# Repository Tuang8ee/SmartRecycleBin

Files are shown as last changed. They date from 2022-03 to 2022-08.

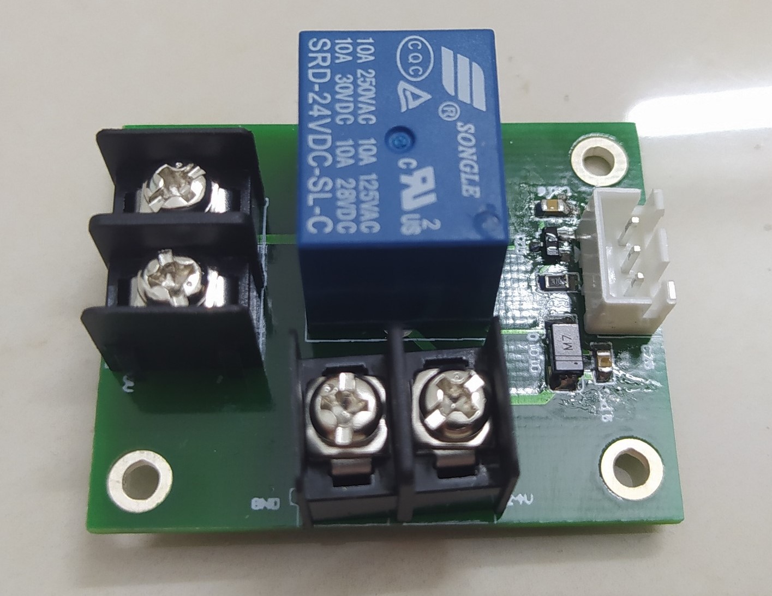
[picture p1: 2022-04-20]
Report/IMG/z3350971799940_279ff23e00b681c5e4f6fa2f28d8ae1a.jpg

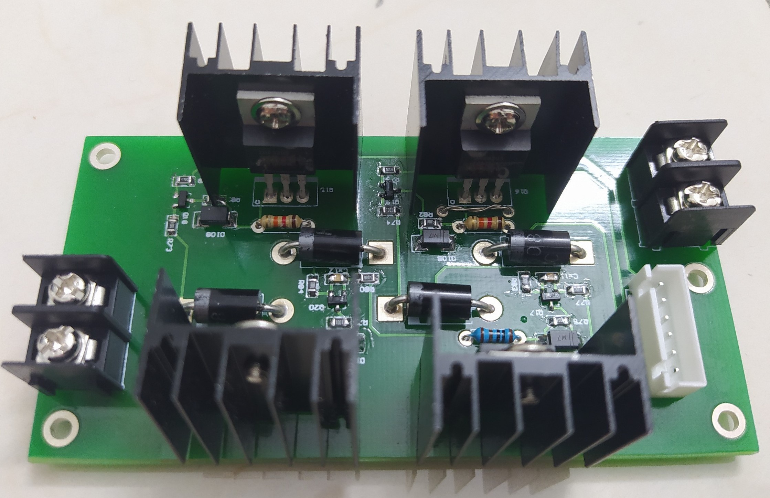
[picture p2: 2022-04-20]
Report/IMG/z3350971804815_c565af6ffac9c361b80e90f9cfdadc9c.jpg

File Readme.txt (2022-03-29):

Đây là git giúp việc gửi file và chia sẻ trong nhóm được dễ dàng hơn. 
Git này phục vụ cho dự án thùng rác thông minh. Mọi người vào nhớ chú ý sắp xếp theo thứ tự thư mục nha.
- Thư mục Report: Lưu lại file báo cáo, các vấn đề liên quan đến báo cáo.
- Thư mục Document: Liên quan đến các tài liệu, doc nếu có.
- Thư mục Project: Sẽ lưu các vấn đề liên quan đến dự án như mạch, thiết kế cơ khí, hay code. Bên trong có các thư mục con:
  + Code
  + Altium
  + CAD
Link data update:
- Link git: https://github.com/Tuang8ee/SmartRecycleBin.git
- Link driver: https://drive.google.com/drive/folders/1032KCYmue00TLKaejduGrtlUdy1hicEE?usp=sharing

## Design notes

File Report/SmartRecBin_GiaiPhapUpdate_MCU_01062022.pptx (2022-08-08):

## SmartRecBin

Dự tính Update mạch điều khiển.

## Giải pháp điều chỉnh mạch điều khiển.

IR Sensor

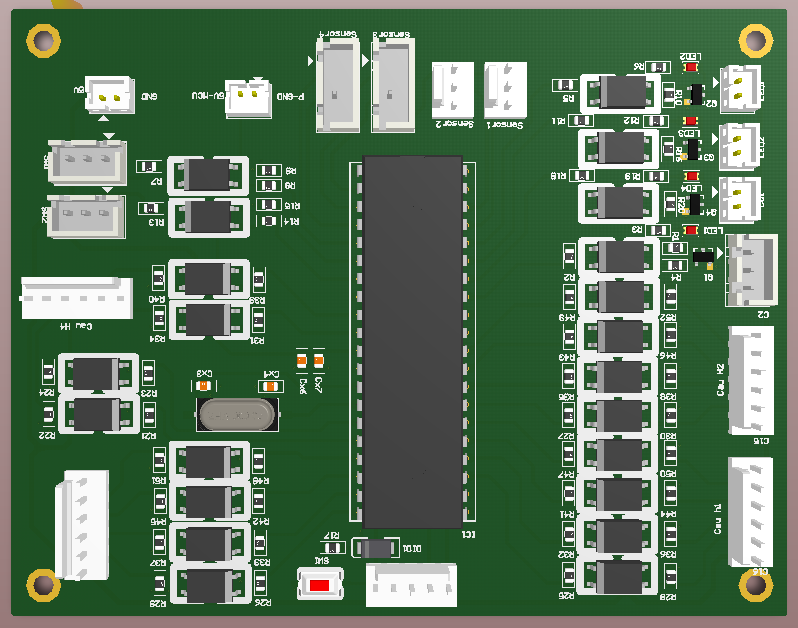
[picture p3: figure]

UltrasonicSensor

1 Buzzer
2 Led

Khử mùi

Button

H: Error

Tời

Compress Motor

UART: RX, TX

UART: RX, TX (TFT)

Door Motor

Hình 1.0: Hình ảnh thể hiện mạch MCU hiện tại và phương hướng phát triển.

Chú thích:

Bị lỗi

Không đổi

Đang dùng

Thay đổi dự kiến

## Giải pháp điều chỉnh mạch điều khiển.

- Chân chưa dung:
  - => Max: Còn 9 chân chưa dùng.
  - => Min: Còn 7 chân chưa dùng (trừ 2 chân I2C).
- Update cảm biến:
  - => Cảm biến LoadCell + HX711: 2 chân.
  - => Cảm biến tời: IR or tiệm cận: 1 chân.
  - => Công tắc hành trình nén: 1 chân.
  - => Công tắc hành trình cửa: 1 chân.
  - => 2 chân chờ Update thêm.
- => Làm mạch nhận tín hiệu cổng OR 2 chân => 1 chân.

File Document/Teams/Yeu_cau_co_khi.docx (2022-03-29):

Mô tả cơ cấu cơ khí nắp thùng rác

Thông tin cơ bản:

- Thông số thùng hiện tại: L:860mm * W:400mm * H:915mm (thân thùng chưa có nắp).
- Cần thiết kế nắp thùng rác cho ba loại thùng khác nhau để đáp ứng các nhu cầu sau:
  - Thùng 1: (T1) thùng đựng vỏ chai nhựa đồ nhựa nhũng rác thải với chất liệu bằng nhựa.
  - Thùng 2: (T2) thùng đựng vỏ lon coca pepsi… những loại rác thải kim loại.
  - Thùng 3: (T3) thùng đựng rác thải hữu cơ.

Mô tả yêu cầu thiết kế cơ khí cho 3 loại thùng rác.

Kích thước nắp thùng mong muốn:

Thông số nắp thùng mong muốn: L:860mm * W:400mm * H:~300mm.

+ Thùng rác (T1) (T2)

- Thùng rác T1, và T2 thiết kế cơ cấu nén rác, vị trí bỏ rác nằm bên cạnh thùng.
- Thiết kế nắp thùng rác gồm có cơ cấu nén rác và có vị trí để mạch nguồn, mạch điều khiển và một acquy 12V.
- Hình ảnh mô tả cơ cấu nén rác và vị đặt của của nắp thùng rác:

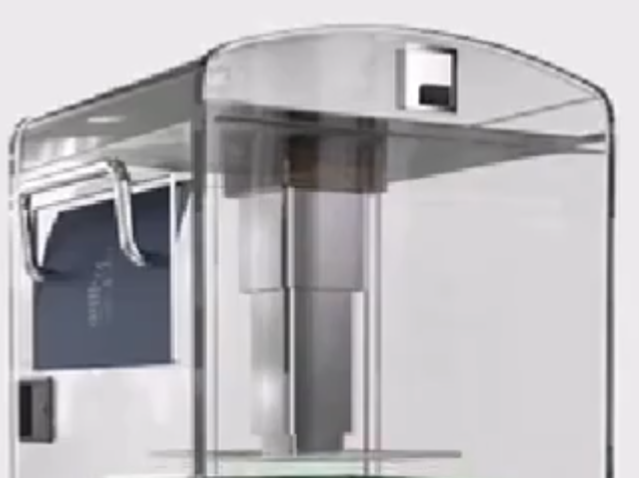
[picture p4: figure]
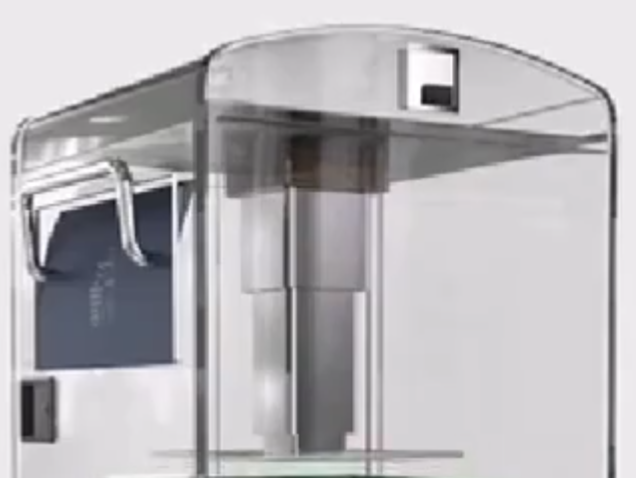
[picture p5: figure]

Khu vực bố trí động cơ mà mạch điều khiển, mạch nguồn, và bố trí acquy

Vị trí bố trí cửa thùng rác (khu vực nắp thùng

Phần cơ cấu nén rác bố trí trên nắp thùng rác

Vị trí bố trí cảm biếm báo đầy rác

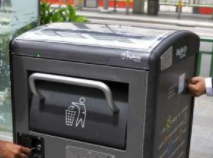
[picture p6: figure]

Phần tay nắm mở nắp thùng rác khi người dùng muốn bỏ rác vào thùng.

- Kiểu nắm mở nắp thùng rác khi người đến vứt rác sẽ kéo tay nắm để bỏ rác vào thùng.

+Thùng rác (T3)

- Thùng rác T3 không có phần nén rác, ở thùng rác T3 thiết kế mở nắp tự động khi có người đến vứt rác.

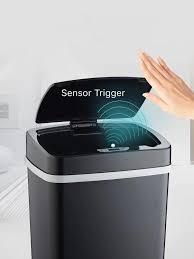
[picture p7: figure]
Automatic Dustbin, Furniture & Home Living, Cleaning & Homecare Supplies, Waste Bins & Bags on Carousell

Vị trí đặt cảm biến

Vị trí đặt cảm biến báo đầy rác

Hình ảnh mô tả cơ chế mở nắp thùng rác

_ Trên mặt thùng rác bố trí cảm biến để nhận biết khi có người đến đổ rác thùng rác sẽ tự động mở nắp.

_ Nắp thùng rác bố trí các vị trí động cơ điều khiển mở đóng nắp thùng rác tự động, vị trí các cảm biến, mạch điều khiển, mạch nguồn và acquy.

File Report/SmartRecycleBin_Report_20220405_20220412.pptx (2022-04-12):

## Thùng rác thông minh

Báo cáo 05/04/2022 – 12/04/2022
(Tuần 3)

## Nội dung thực hiện:

- Tiến hành đặt mạch in.
- Hoàn thành đặt linh kiện.
- Hoàn thiện file cơ khí.
- Bắt đầu viết chương trình điều khiển.

## Kết quả:

- Tiến hành đặt mạch in:
  - Cơ sở đặt mạch: VNPCB – HAVICOM.
  - Địa chỉ: Số 77 LK23 – KĐT Vân Canh HUD, Hoài Đức, Hà Nội.
  - Thời gian đặt mạch: 08/04 – 15/04. (4 – 5 ngày làm việc, nghỉ lễ giỗ tổ Hùng Vương nên bị chậm 3 ngày so với kế hoạch đẩy nhanh tiến độ tuần 2).
- Đặt linh kiện:
  - Đã tiến hành đặt và order linh kiện. Hiện tại đã đủ linh kiện để hoàn thành mạch khi mạch về.

## Kết quả:

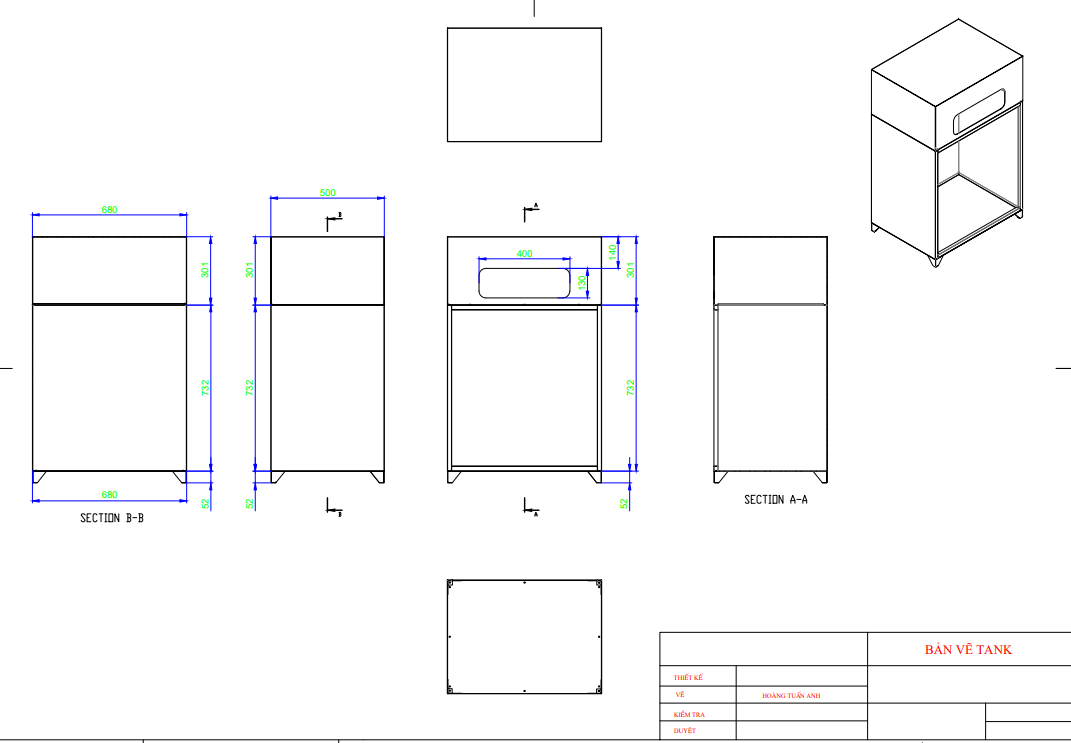
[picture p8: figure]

- Hoàn thiện file cơ khí:

Hình 1: Hình ảnh miêu tả bản vẽ cơ khí tổng quát thùng rác.

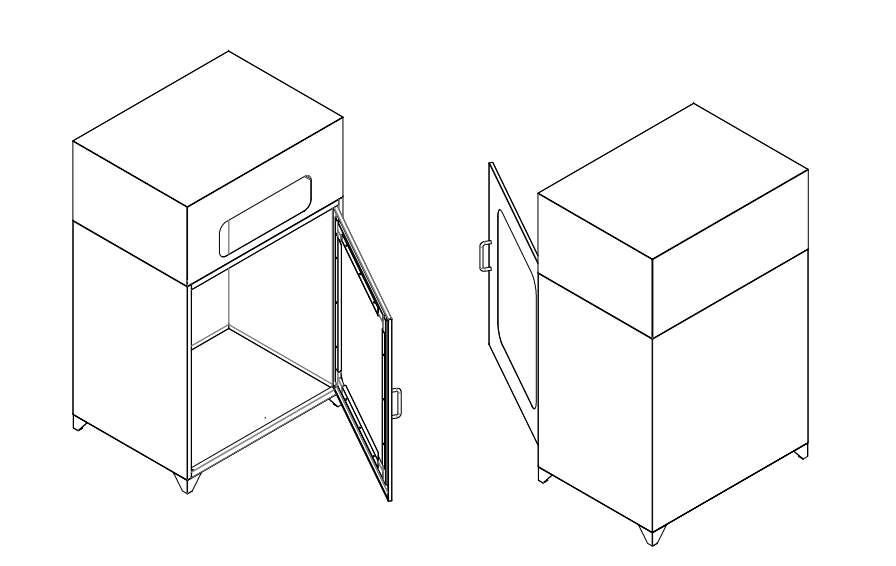
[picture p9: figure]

## Kết quả:

- Hoàn thiện file cơ khí:

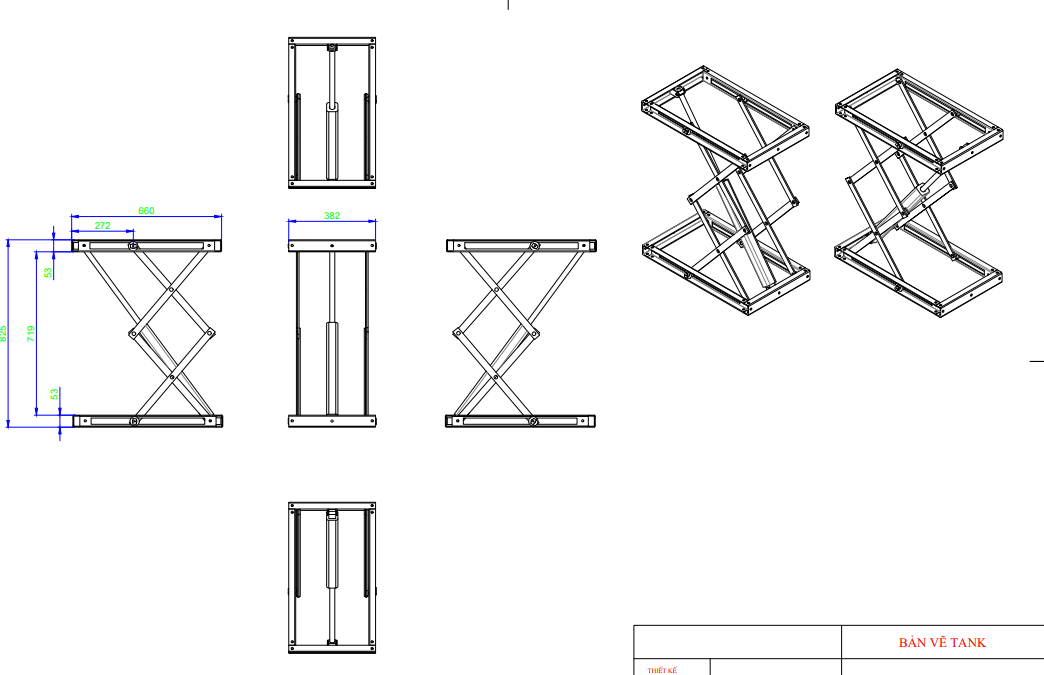
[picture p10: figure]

Hình 2: Hình ảnh miêu tả bản vẽ cơ khí một số phần của sản phẩm.

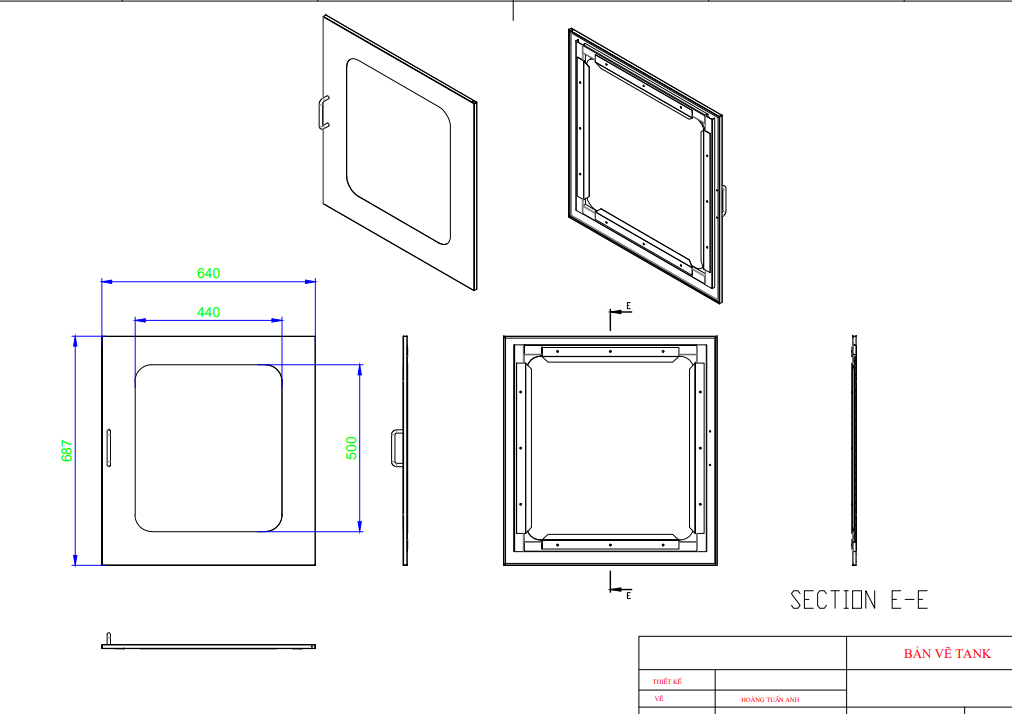
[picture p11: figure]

## Vấn đề còn gặp phải.

- Tiến độ dự án:
Hiện tại tiến độ dự án chậm hơn so với kế hoạch đặt ra, cụ thể:
Kế hoạch vẫn chậm hơn 8 ngày so với dự kiến. Trong giai đoạn đặt mạch không thể rút ngắn thêm thời gian. Vì thế thời gian dự kiến sẽ được update trong bảng timeline phía dưới.
- Nội dung dự án:
  - Còn một số vấn đề cần thống nhất trước khi gửi bản vẽ gia công cơ khí. Cụ thể:
    - Cần trao đổi và chốt một số phương án thiết kế chi tiết phía trong bản vẽ cơ khí.
    - Xác nhận thông số trước khi gửi thông tin bản thiết kế cho sản phẩm demo lần 1.

## Phương án giải quyết và kế hoạch tiếp theo.

- Đề xuất phương án:
  - Trao đổi thống nhất một số thông số chung trước khi gửi file hoàn thiện.
  - Update timeline mới:
- Kế hoạch tuần tiếp theo:
  - Hoàn thiện mạch, sẵn sàng cho sản phẩm demo.
  - Gia công cơ khí.
  - Chuẩn bị kịch bản test và demo.

## Phương án giải quyết và kế hoạch tiếp theo.

  - Update timeline mới:

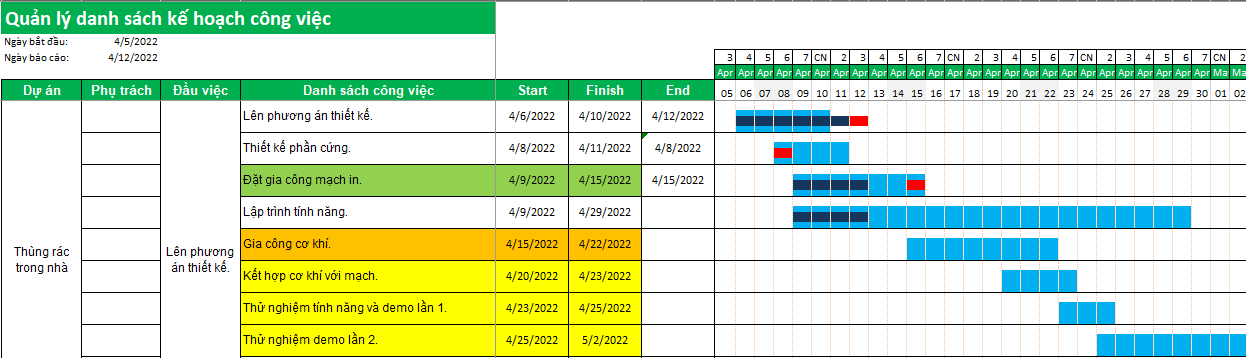
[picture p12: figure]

Hình 3: Hình ảnh miêu tả bản update timeline dự kiến cho thời gian tới.

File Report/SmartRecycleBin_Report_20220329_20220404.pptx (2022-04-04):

## Thùng rác thông minh

Báo cáo 29/03/2022 – 04/04/2022

## Nội dung thực hiện:

- Hoàn thành sơ đồ nguyên lý của mạch. Hoàn thành bản vẽ bố trí linh kiện, mô phỏng 3D mạch.
- Đưa ra phương án thiết kế cơ cấu nén rác, cắt nhỏ, nghiền cho thùng rác chưa túi nilon, thùng rác chứa vỏ lon và vỏ chai nhựa.
- Chuẩn bị linh kiện, động cơ cho sản phẩm.

## Kết quả:

- Hoàn thành sơ đồ nguyên lý của mạch. Hoàn thành bản vẽ bố trí linh kiện, mô phỏng 3D mạch:

## Kết quả:

- Phương án thiết kế bộ phận nén cho thùng rác túi nilon: Thiết kế cơ cấu nén rác theo cơ cấu hình chữ X:

Hình 1: Hình ảnh miêu tả ý tưởng thiết kế cơ chế nén thùng rác.

Thùng rác nilon

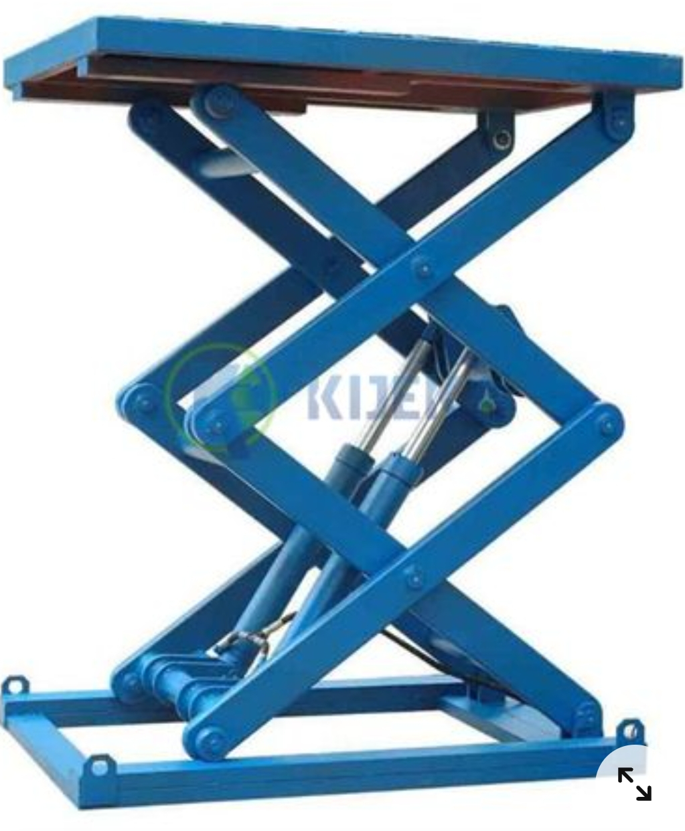
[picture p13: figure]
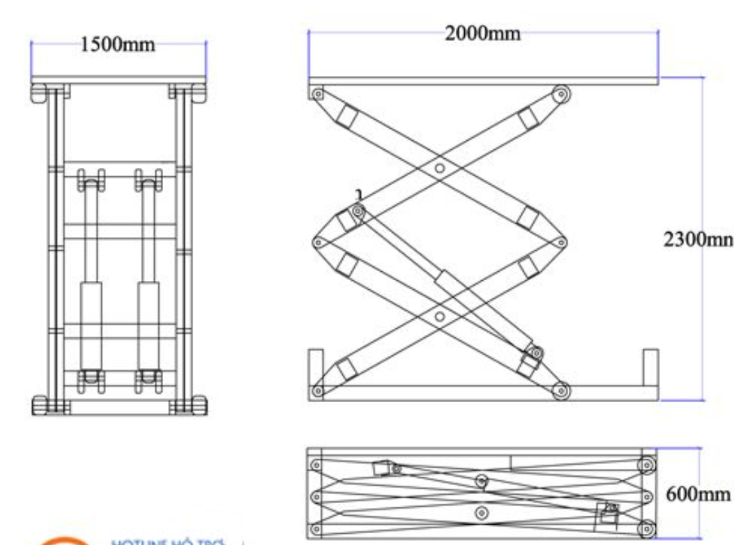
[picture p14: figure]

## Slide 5

Phương án thiết kế bộ phận nén cho thùng rác túi nilon: Thiết kế cơ cấu nén rác theo cơ cấu hình chữ X:

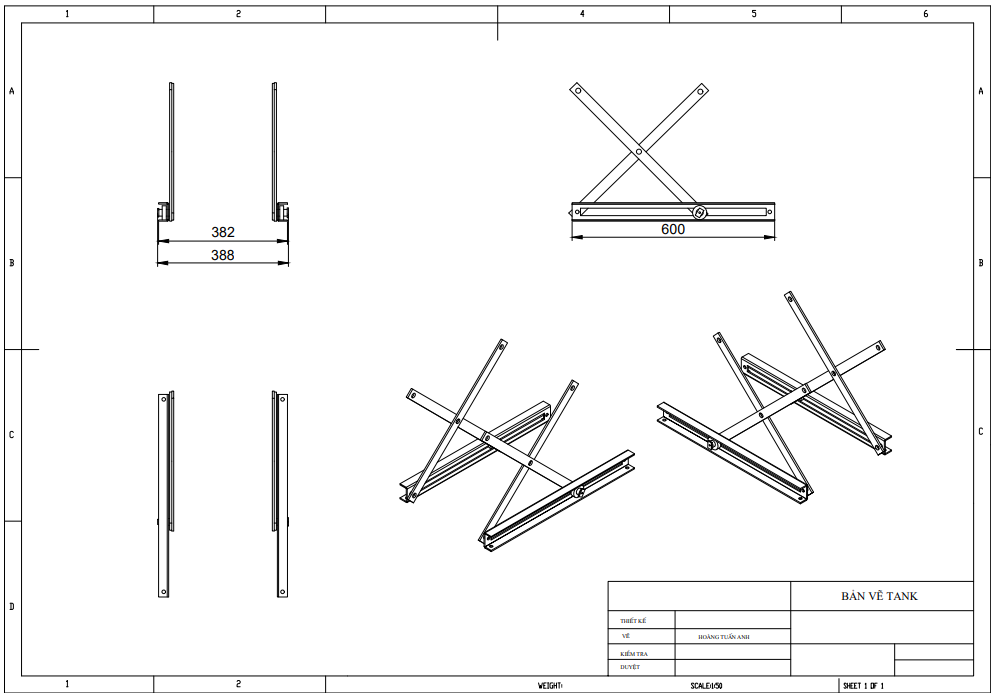
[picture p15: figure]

Hình 2: Hình ảnh mô tả cơ cấu chữ X thực tế sẽ thiết kế theo kích thước thùng dựa trên file phương án.

## Kết quả:

- Phương án thiết kế cho thùng rác chưa kím loại và nhựa:

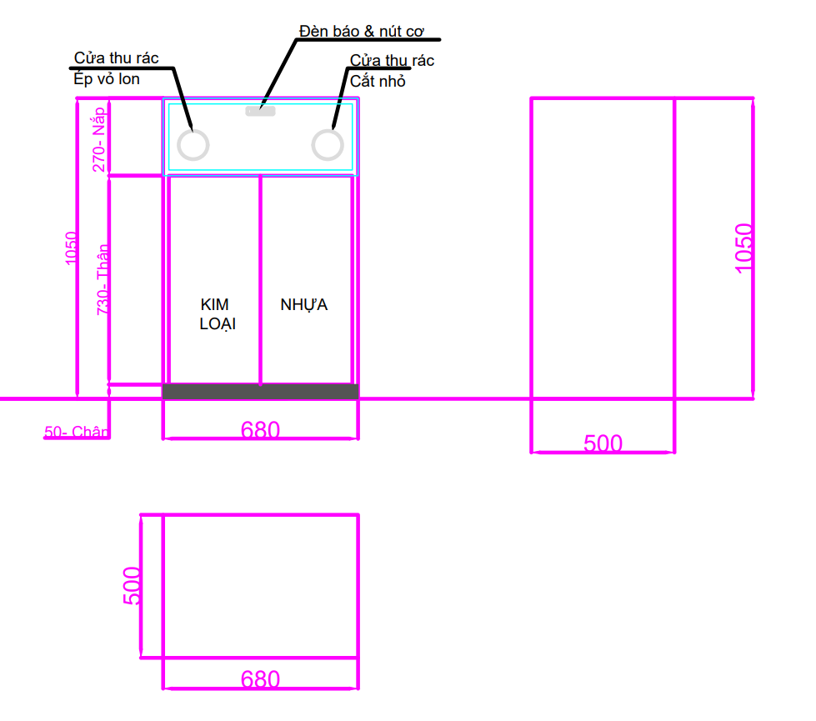
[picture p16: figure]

Hình 3: Hình ảnh miêu tả phương án theo file phương án.

Một bên chứa cơ cấu nén vỏ lon trực tiếp theo từng lon được bỏ vào.

Có thể ép hầu hết các lon phổ thông trên thị trường hiện nay.

Bên còn lại chứa cơ cấu nghiền, cắt nhỏ vỏ chai nhựa, theo từng chai nhựa được bỏ vào.

Chai có dung tích <1.5L

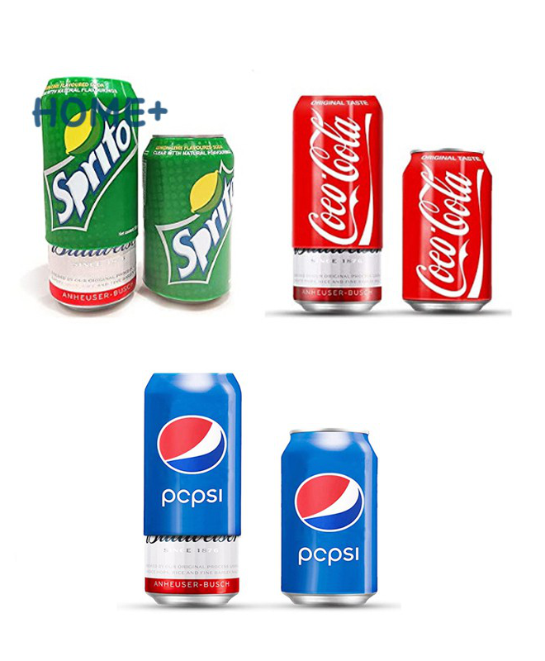
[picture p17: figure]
Hàng Mới Về) Vỏ Silicone Bọc Lon Bia 355ml Tiện Dụng | Shopee Việt Nam
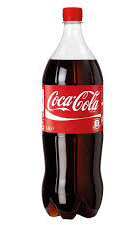
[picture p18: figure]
DetailsProductMobile

## Kết quả:

- Phương án thiết kế cho thùng rác chưa kím loại và nhựa:
  - Cơ cấu nén vỏ lon:
    - Xử dụng piston điện, có lực đẩy >50Kg
    - Nén trực tiếp từng lon kim loại được bỏ vào.

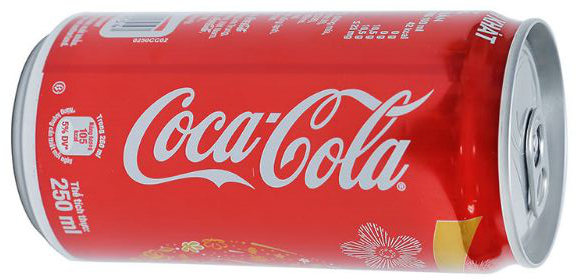
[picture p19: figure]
Siêu mới 1 lon coca vị nguyên bản 250ml | Shopee Việt Nam
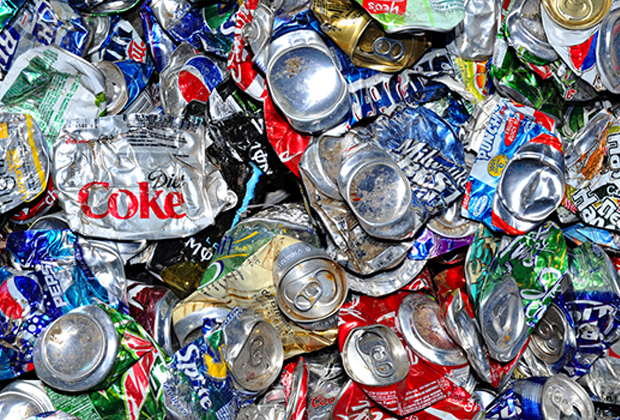
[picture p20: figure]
THU MUA VỎ LON BIA PHẾ LIỆU, VỎ CHAI NƯỚC NGỌT GIÁ CAO

Hình 4: Hình ảnh miêu tả phương án nén vỏ lon

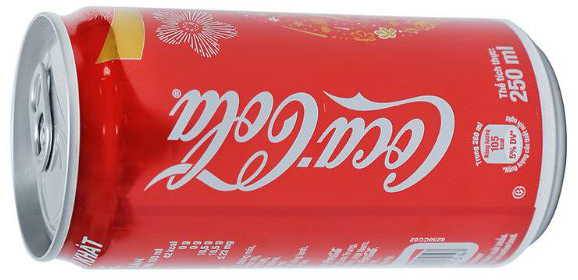
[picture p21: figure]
Siêu mới 1 lon coca vị nguyên bản 250ml | Shopee Việt Nam

## Kết quả:

- Phương án thiết kế cho thùng rác chưa kím loại và nhựa:
  - Cơ cấu cắt vỏ nhựa:
    - Phương án 1: Sử dụng nhiều lưỡi cắt, cắt nhỏ.
    - Phương án 2: Sử dụng cơ chế máy nghiền rác.

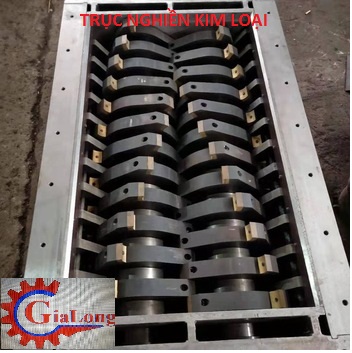
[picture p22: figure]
Máy nghiền rác thải công nghiệp - cokhigialong

Phương án 2: Sử dụng cơ chế bánh rang để nghiền nhỏ chai nhựa.

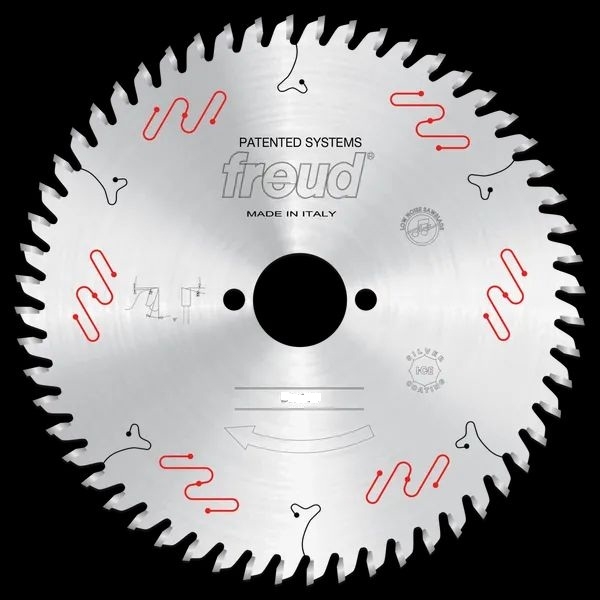
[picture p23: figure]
Lưỡi cưa cắt nhựa 178mm/80T FREUD LU4B-0500
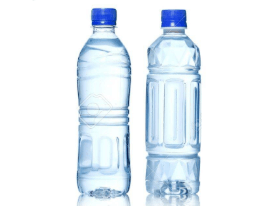
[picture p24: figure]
Chai nhựa đựng nước ép, nước sâm chất lượng tốt giá rẻ tại TP.HCM

Phương án 1: Sử dụng nhiều lưỡi cắt để cắt chai nhựa.

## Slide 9

Mô tả phương án 1: Sử dụng nhiều lưỡi cắt, cắt nhỏ.

Lưỡi cưa

Cửa bỏ vỏ nhựa

Chai nhựa.

Tấm ép. Sẽ di chuyển gần về lưỡi cưa, ép vỏ chai nhựa tiến gần vào lưỡi cưa để cắt.

Mô tả:
Chai nhựa (màu vàng) sau khi được bỏ vào bằng cửa (màu trắng) sẽ được bộ phận ép (màu cam) ép lại gần các lưỡi cưa song song đồng trục (màu đen). Khi tiến lại gần sẽ ép vỏ chai nhựa bị cắt thành nhiều mảnh nhỏ.

Hình 5: Hình ảnh miêu tả phương án 1 để cắn nhỏ vỏ nhựa.

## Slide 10

Mô tả phương án 2: Sử dụng cơ chế máy nghiền rác:
(Chưa hoàn thành)

## Phương án giải quyết và kế hoạch tiếp theo.

- Đề suất phương án:
  - Hoàn thành thành mô tả thêm phương án 2 cho thùng rác xử lý vỏ lon, vỏ nhựa.
  - Đánh giá tính khả thi của 2 phương án.
- Kế hoạch tuần tiếp theo:
  - Hoàn thành bản vẽ mô tả chi tiết bằng file CAD cho cơ chế nén rác thùng rác nilon.
  - Đưa ra nhận xét, đánh giá, giải pháp cho cơ chế nghiền cắt vỏ nhựa.
  - Hoàn thành bản vẽ chi tiết bằng file CAD cho cơ chế nén vỏ lon.
  - Gửi gia công mạch PCB.
  - Viết chương trình điều khiển cho mạch.

## Đề suất.

- Sau khi đã có phương án cơ khí, chúng em nhận thấy cấu tạo cơ khí bộ phận nén rác túi nilon là khả thi. Qua quá trình tìm giải pháp, bên chúng em đã có sơ bộ bản vẽ, thiết kế cơ khí cho cơ cấu nén.
- Vì vậy chúng em xin đề suất được tự tiếp tục thiết kế hoàn thiện bản vẽ cho phần cơ cấu nén rác này và xin phép được tự gia công riêng phần cơ cấu nén rác để có một bản mẫu đánh giá chạy thử nghiệm riêng cho phần cơ cấu nén.
- Thời gian dự kiến test cơ cấu: 10/04 – 16/04
- Kết quả đánh giá: Trong và ngay sau thời gian test.

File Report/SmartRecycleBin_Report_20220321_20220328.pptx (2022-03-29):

## Thùng rác thông minh

Báo cáo 21/03/2022 – 28/03/2022

## Nội dung thực hiện:

- Thiết kế sơ đồ nguyen lý mạch điều khiển trung tâm, mạch điều khiển động cơ, mạch cảm biến.
- Đưa ra file mô tả thiết kế thùng rác:
- Tìm giải pháp thực hiện cơ khí.
- Đưa ra ý tưởng cho bản vẽ cơ khí.
- Tìm môi trường thi công.

## Kết quả:

- Thiết kế sơ đồ nguyên lý mạch điều khiển trung tâm, mạch điều khiển động cơ, mạch cảm biến:
  - Đã đưa ra được sơ đồ khối hệ thống, tín toán cho bản vẽ thiết kế mạch.
  - Sơ đồ khối của hệ thống điều khiển: Slide 3
  - Đã thiết kế xong phần mạch điều khiển trung tâm, mạch điều khiển đầu ra, mạch cảm biến.

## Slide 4

Sơ đồ khối của hệ thống điều khiển

Khối nguồn

Mạch nguồn chính

Acquy

Mạch điều khiển nguồn acquy

Mạch chuyển đổi nguồn

Điện dân dụng

Khối điều khiển đầu ra

Mở nắp

Nén rác

Khử mùi

Piston điện mở nắp

Máy nén

Máy bơm áp suất

Đèn hiển thị
Còi báo tín hiệu

Khối cảm biến

Mở nắp

Báo đầy rác

Khối điều khiển trung tâm.

Hình 1: Sơ đồ khối của hệ thống điều khiển.

## Kết quả:

- Đưa ra file mô tả thiết kế thùng rác:
  - Tìm giải pháp, đưa ra file mô tả cơ bản ban đầu trước khi thiết kế.
  - File: Yêu cầu cơ cấu cơ khí nắp thùng rác.
- Đưa ra ý tưởng cho bản vẽ cơ khí.
  - Lên kế hoạch, ý tưởng cho bản vẽ cơ khí và triển khai.
  - Bắt đầu vẽ bản vẽ phác thảo cho phần cơ khí với ý tưởng được đưa ra ở file yêu cầu cơ cấu cơ khí nắp thùng rác.
- Tìm môi trường thi công.
  - Chưa tìm được.

## Vấn đề gặp phải:

- Đưa ra ý tưởng cho bản vẽ cơ khí.
  - Cơ cấu cơ khí phức tạp, không thể hoàn thành sớm được.
  - Theo dự kiến sẽ yêu cầu thi công luôn, tuy nhiên do cần phải có bản vẽ cơ khí trước nên thời gian dự kiến thi công cơ khí sẽ bị chậm. Thông tin bản vẽ kĩ thuật cơ khí:
    - Thời gian dự kiến cho bản vẽ phác thảo đầu tiên (kèm video minh họa): 7 ngày kể từ khi bắt đầu vẽ.
    - Thời gian dự kiến vẽ các chi tiết bên trong: 7 – 10 ngày sau khi có bản phác thảo.
    - Thời gian có bản vẽ hoàn thiện: Ngay sau khi thống nhất hoàn các chi tiết bên trong.
  - Chỉ thiết kế phần nắp thùng dựa trên thông số phần thân thùng. Một số vấn đề cần làm rõ:
    - Kích thước theo thân thùng (Ảnh 2 – slide 7): 860 x 400 x 915 (mm).
    - Phần kích thước nêu trên khi thiết kế nắp có được phép thiết kế lơn hơn so với kích thước này hay không.
    - Các thông số a, b, c, d (Minh họa như phần màu vàng trong ảnh 3 – slide 7) cho phép là bao nhiêu?.
  - Có chi phí phát sinh:
    - Phát sinh thêm về bản vẽ cơ khí so với báo giá 22/3.

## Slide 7

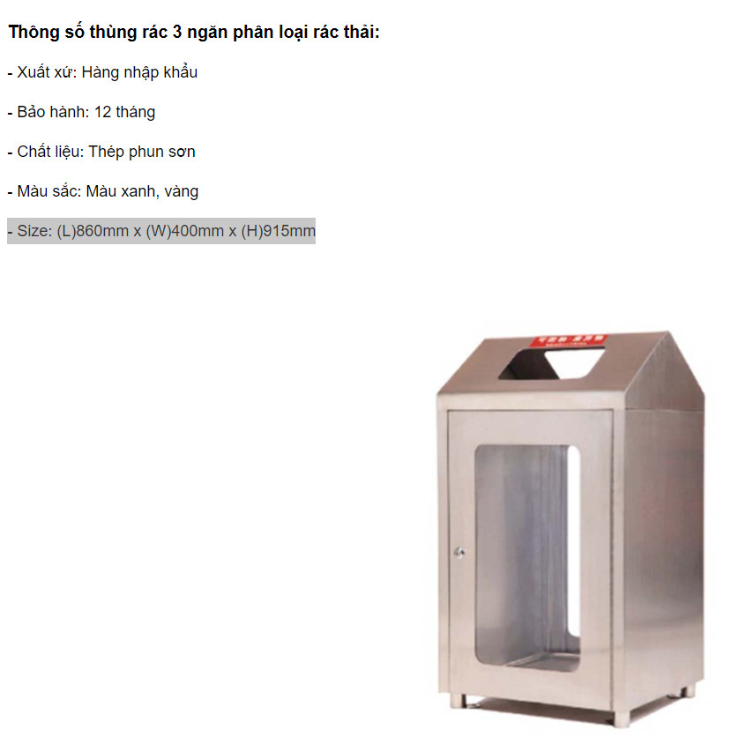
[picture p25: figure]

Hình 2: Thông số thùng rác đã có.

b

1

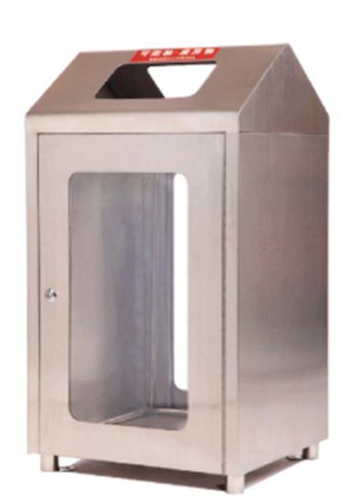
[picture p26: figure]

2

3

c

a

d

Hình 3: Miêu tả vấn đề gặp phải.

## Phương án giải quyết và kế hoạch tiếp theo.

- Phương án:
  - Update timeline, chỉnh sửa lại kế hoạch để đảm bảo tiến độ.
  - Cần tính toán lại dự toán cho sản phẩm. Chi phí phát sinh thêm có thể có, chi tiết sẽ được gửi ngay sau khi có bản vẽ phác thảo dự kiến cơ khí (3 – 4 ngày sau khi bắt đầu vẽ).
- Kế hoạch tuần tiếp theo:
  - Thiết kế mạch:
    - Hoàn thiện sơ đồ nguyên lý và mạch 3D.
    - Gửi yêu cầu đặt mạch.
  - Vẽ phác thảo bản vẽ cơ khí, kèm video minh họa.
  - Viết chương trình điều khiển cơ bản cho mạch.
  - Gửi lại dự toán và timeline tiếp theo.

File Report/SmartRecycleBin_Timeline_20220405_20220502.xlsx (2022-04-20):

Quản lý danh sách kế hoạch công việc
Ngày bắt đầu: | 2022-04-05
Ngày báo cáo: | 2022-04-19 |  |  |  |  |  | 3 | 4 | 5 | 6 | 7 | CN | 2 | 3 | 4 | 5 | 6 | 7 | CN | 2 | 3 | 4 | 5 | 6 | 7 | CN | 2 | 3 | 4 | 5 | 6 | 7 | CN | 2 | 3 | 4 | 5 | 6 | 7 | CN | 2 | 3 | 4 | 5 | 6 | 7 | CN | 2 | 3 | 4 | 5 | 6 | 7 | CN | 2 | 3 | 4 | 5
 |  |  |  |  |  |  | Apr | Apr | Apr | Apr | Apr | Apr | Apr | Apr | Apr | Apr | Apr | Apr | Apr | Apr | Apr | Apr | Apr | Apr | Apr | Apr | Apr | Apr | Apr | Apr | Apr | Apr | May | May | May | May | May | May | May | May | May | May | May | May | May | May | May | May | May | May | May | May | May | May | May | May | May | May
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

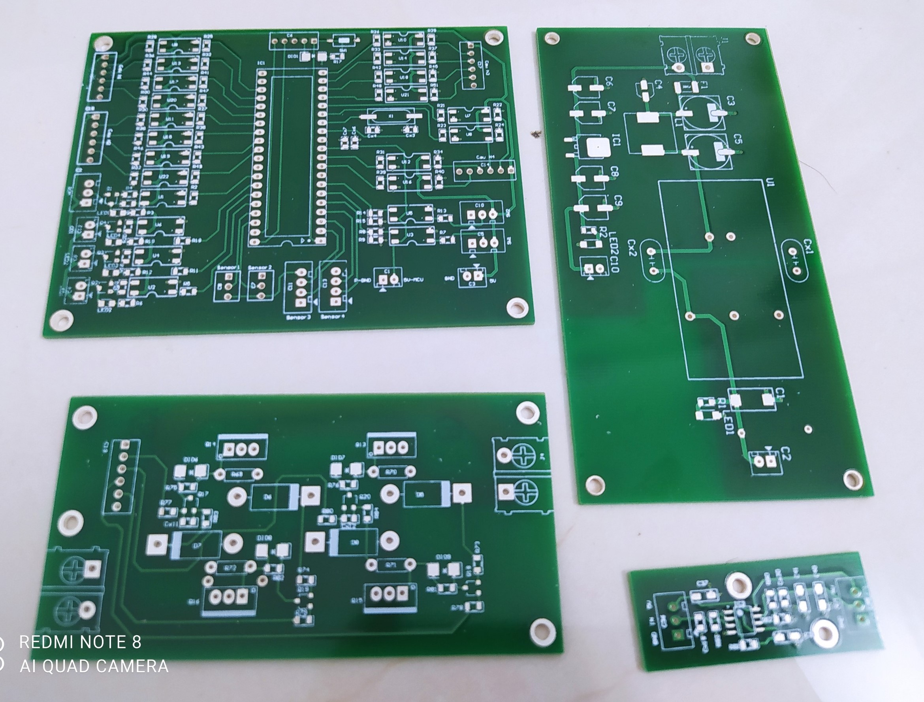
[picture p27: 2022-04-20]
Report/IMG/z3350971798660_095ca763fae1163586489f47b80bea36.jpg

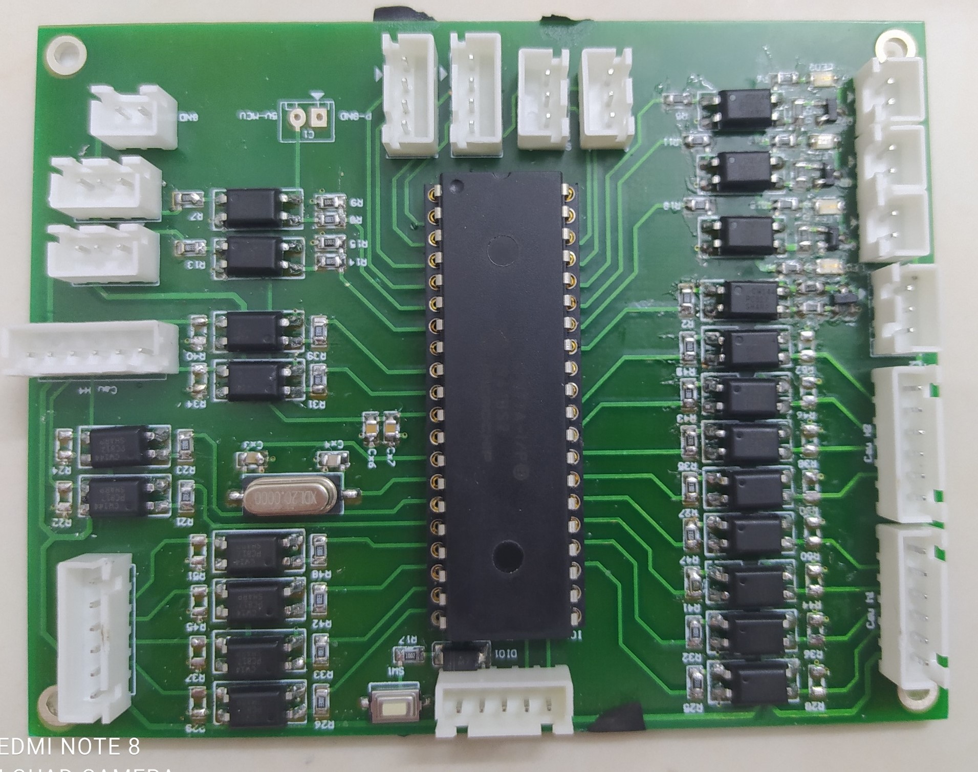
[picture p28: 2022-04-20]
Report/IMG/z3350971802484_e587b620290664b9014640a109312455.jpg

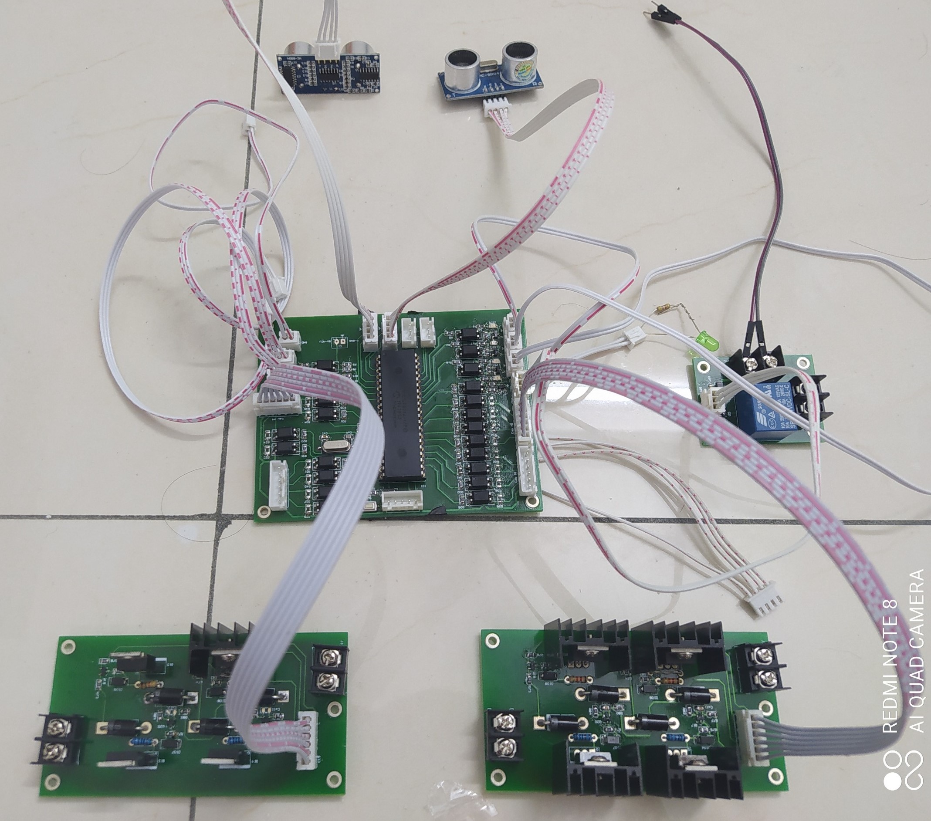
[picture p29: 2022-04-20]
Report/IMG/z3350971805744_79a449336ed9d9e2291ec2d6de25ad3a.jpg

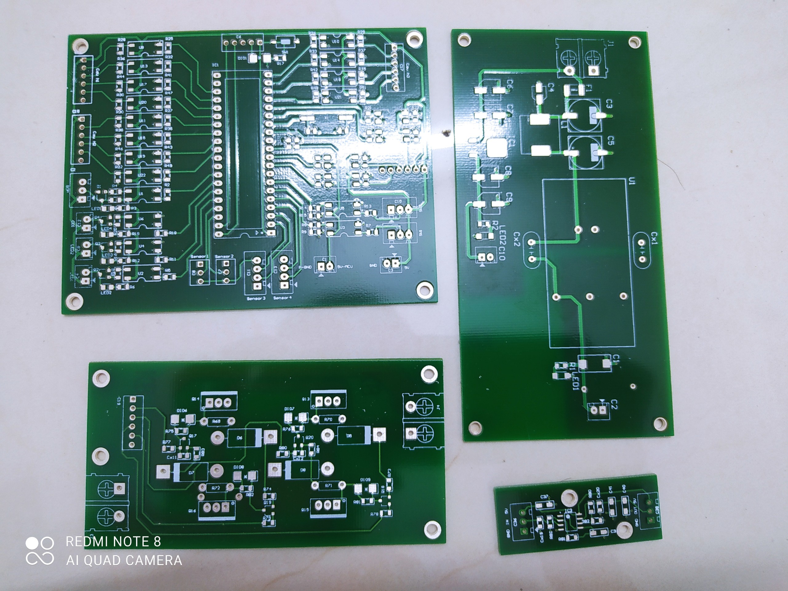
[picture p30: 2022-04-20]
Report/IMG/z3350971799133_88eee4026867727fb467489302b8d04a.jpg

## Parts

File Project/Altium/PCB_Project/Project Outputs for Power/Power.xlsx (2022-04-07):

Comment | Description | Designator | Footprint | LibRef | Quantity
470uF/10V | http://linhkienchatluong.vn/tu-tantalium/tu-tantalum-7343-477a-10v-470uf-73x43mm_sp460_ct1168.aspx | C1 | TANTALUM-7343 | CN-TANTALUM-SMD | 1
Header2 | http://linhkienchatluong.vn/header-xh254-trang/header-duc-2p-xh254-2p-chan-thang-10c_sp861_ct1711.aspx, Header IDC, 2 x 1 Pin Vertical 2.54mm Pitch (Non-Boxed, Male) | C2, C10 | Header2 | Header2 | 2
330uF/50V | http://linhkienchatluong.vn/tu-nhom---tu-hoa-dan/tu-nhom-50v-330uf-10x102mm_sp455_ct2883.aspx, Polarized Capacitor (Axial) | C3, C5 | CAP-ALU-SMD-G | CN-ALU-SMD | 2
1uF/50V | http://linhkienchatluong.vn/tu-nhom---tu-hoa-dan/tu-nhom-50v-1uf-4x55mm_sp455_ct981.aspx | C4 | CAP-ALU-SMD-4.5x5x1.4 | CN-ALU-SMD | 1
220uF/50V | Polarized Capacitor (Axial), http://linhkienchatluong.vn/tu-nhom---tu-hoa-dan/tu-nhom-16v-220uf-63x77mm_sp455_ct964.aspx | C6, C7, C8, C9 | CAP-ALU-SMD-6.3x7.7x2.2 | CN-ALU-SMD | 4
1nF/2kV |  | Cx1, Cx2 | CN2-B | CN | 2
F3A | http://linhkienchatluong.vn/cau-chi-su-smd-1808/cau-chi-su-smd-3a-125v-61x269mm-1808-fast-blow-fuse_sp1022_ct7321.aspx | F1 | FUSE_SMD 1812 | Fuse | 1
LM7805 | http://linhkienchatluong.vn/ic-on-ap-78xx-79xx/78m05-05a-5v-to-252-chinh-hang-st_sp1000_ct8359.aspx | IC1 | TO252-123 | LM78xx | 1
KF2 | http://linhkienchatluong.vn/cau-dau-kf762/cau-dau-2p-kf762-2p-762mm-mau-den-loai-tot_sp871_ct5960.aspx | J1 | KF2-7.62 | KF2 | 1
4.7uH | http://linhkienchatluong.vn/cuon-cam-dan-cd127-12x12x7mm/cuon-cam-dan-cdrh127-47uh-4r7-3a-12x12x7mm_sp842_ct3447.aspx | L1 | L-SMD-M-12x10 | L-SMD-1 | 1
LED |  | LED1, LED2 | LED-1206-Red | LED SMD | 2
470 | Resistor | R1, R2 | RES-SMD-0805 | Res-SMD | 2
SLW05B-05 |  | U1 | SLW05B-05 | Module DC-DC 220/5V/5W | 1

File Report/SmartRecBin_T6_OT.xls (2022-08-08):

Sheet: TIMESHEET
TIMESHEET - THỜI GIAN LÀM VIỆC VỚI VHEC TRONG THÁNG 5
Họ và tên | Nguyễn Ngọc Tuấn
Period Beginning: |  | 2022-06-24
DATE | Day | Hours Worked | Holiday Hours | Medical Leave Hours | Personal Leave Hours | Total Hours for Day | TASK OR WORK PACKAGE ID
2022-06-24 | Friday | 4.0 | 0.0 | 0.0 | 0.0 | 4.0 | + Vẽ nguyên lý. (Đạt) + Lên phương án tời. (Đạt) + Chuyển về 1 động cơ. Đổi lại kích thước bàn cân. (Huy)
2022-06-25 | Saturday | 4.0 | 0.0 | 0.0 | 0.0 | 4.0 | + Layout mạch + lên danh sách linh kiện. (Huy). + Xin và chuẩn bị đồ cơ cấu tời. (Đạt + Tuấn). + Nếu kịp thì làm cơ cấu tời. (Đạt + Tuấn). + Nếu không kịp: Làm khung, bàn trượt của chữ X cho thùng 2. (50%)
2022-06-26 | Sunday | 8.0 | 0.0 | 0.0 | 0.0 | 8.0 | (Tuấn + Đạt + Huy) + Hoàn thiện khung, bàn trượt cơ cấu chữ X của thùng 2 (V1.1). + Thêm hệ thống phun sương. + Nếu còn thời gian: Làm mở cửa hoặc tời.
2022-06-27 | Monday | 4.0 | 0.0 | 0.0 | 0.0 | 4.0 | + Đặt mạch - xin báo giá làm mạch. (Huy). + Xin bill của linh kiện mạch. (Huy). + Hoàn thiện tời + mở cửa. (Đạt + Tuấn + Huy)
2022-06-28 | Tuesday | 3.0 | 0.0 | 0.0 | 0.0 | 3.0 | + Tiếp tục cơ khí, chuẩn bị cho cơ cấu thùng V1.2.
2022-06-29 | Wednesday | 4.0 | 0.0 | 0.0 | 0.0 | 4.0 | + Tiếp tục cơ khí, chuẩn bị cho cơ cấu thùng V1.2.
2022-06-30 | Thursday | 4.0 | 0.0 | 0.0 | 0.0 | 4.0 | + Tiếp tục cơ khí, chuẩn bị cho cơ cấu thùng V1.2.
2022-07-01 | Friday | 4.0 | 0.0 | 0.0 | 0.0 | 4.0 | + Tiếp tục cơ khí, chuẩn bị cho cơ cấu thùng V1.2.
2022-07-02 | Saturday | 4.0 | 0.0 | 0.0 | 0.0 | 4.0 | + Hàn mạch: (Đạt + Huy).
2022-07-03 | Sunday | 8.0 | 0.0 | 0.0 | 0.0 | 8.0 | + Test mạch (MCU, Cầu H, Nguồn…) (Đạt + Huy)
2022-07-04 | Monday | 4.0 |  |  |  | 4.0 | + Update mạch mới cho cơ cấu thùng V1.1, V1.2
2022-07-05 | Tuesday | 4.0 |  |  |  | 4.0 | Điều chỉnh sau
2022-07-06 | Wednesday | 4.0 |  |  |  | 4.0 | Điều chỉnh sau
2022-07-07 | Thursday | 4.0 |  |  |  | 4.0 | Điều chỉnh sau
2022-07-08 | Friday | 4.0 |  |  |  | 4.0 | Điều chỉnh sau
2022-07-09 | Saturday | 4.0 |  |  |  | 4.0 | Điều chỉnh sau
2022-07-10 | Sunday |  |  |  |  | 0.0 | Điều chỉnh sau
2022-07-11 | Monday |  |  |  |  | 0.0
2022-07-12 | Tuesday |  |  |  |  | 0.0
2022-07-13 | Wednesday |  |  |  |  | 0.0
2022-07-14 | Thursday |  |  |  |  | 0.0
2022-07-15 | Friday |  |  |  |  | 0.0
2022-07-16 | Saturday |  |  |  |  | 0.0
2022-07-17 | Sunday |  |  |  |  | 0.0
2022-07-18 | Monday |  |  |  |  | 0.0
2022-07-19 | Tuesday |  |  |  |  | 0.0
2022-07-20 | Wednesday |  |  |  |  | 0.0
2022-07-21 | Thursday |  |  |  |  | 0.0
2022-07-22 | Friday |  |  |  |  | 0.0
2022-07-23 | Saturday |  |  |  |  | 0.0
Totals: |  | 71.0 | 0.0 | 0.0 | 0.0 | 71.0 | COMMENTS
Total Hours Accounted for: |  | 71.0
Supervisor's Signature: Signature verifies & approves hours served / leave taken.

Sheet: RESOURCES
Create and track your tasks with MeisterTask (https://www.meistertask.com/?r=185086)
ClickUp - One place for all your work. Save one day a week! (https://clickup.com/?fp_ref=tamzin95)
Clockify - free time tracker for teams (https://clockify.me/)

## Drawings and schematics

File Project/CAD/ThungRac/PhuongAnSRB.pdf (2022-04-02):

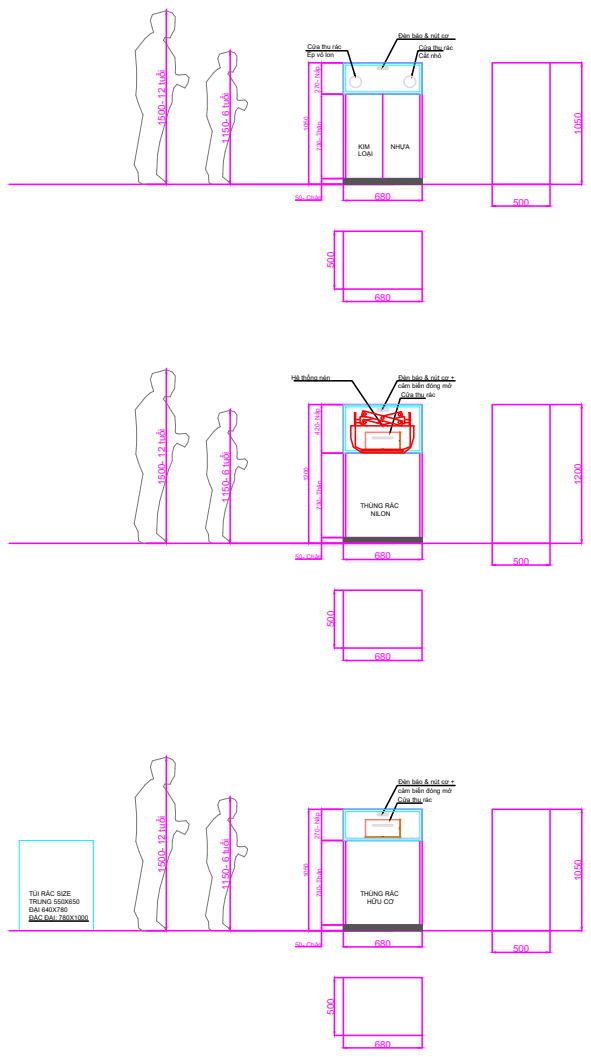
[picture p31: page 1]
1150- 6 tuổi 50- Chân; 730- Thân; 270- Nắp 500; 1200 50- Chân; 420- Nắp; 1150- 6 tuổi; 1500- 12 tuổi

1050 Đèn báo & nút cơ Cửa thu rác Cắt nhỏ

1500- 12 tuổi KIM LOẠI NHỰA Cửa thu rác Ép vỏ lon

150 300 Đèn báo & nút cơ + cảm biến đóng mở Cửa thu rác THÙNG RÁC NILON Hệ thống nén

1500- 12 tuổi THÙNG RÁC HỮU CƠ 680

150 300 Đèn báo & nút cơ + cảm biến đóng mở Cửa thu rác

500 680 TÚI RÁC SIZE TRUNG 550X650 ĐẠI 640X780 ĐẶC ĐẠI: 780X1000 680

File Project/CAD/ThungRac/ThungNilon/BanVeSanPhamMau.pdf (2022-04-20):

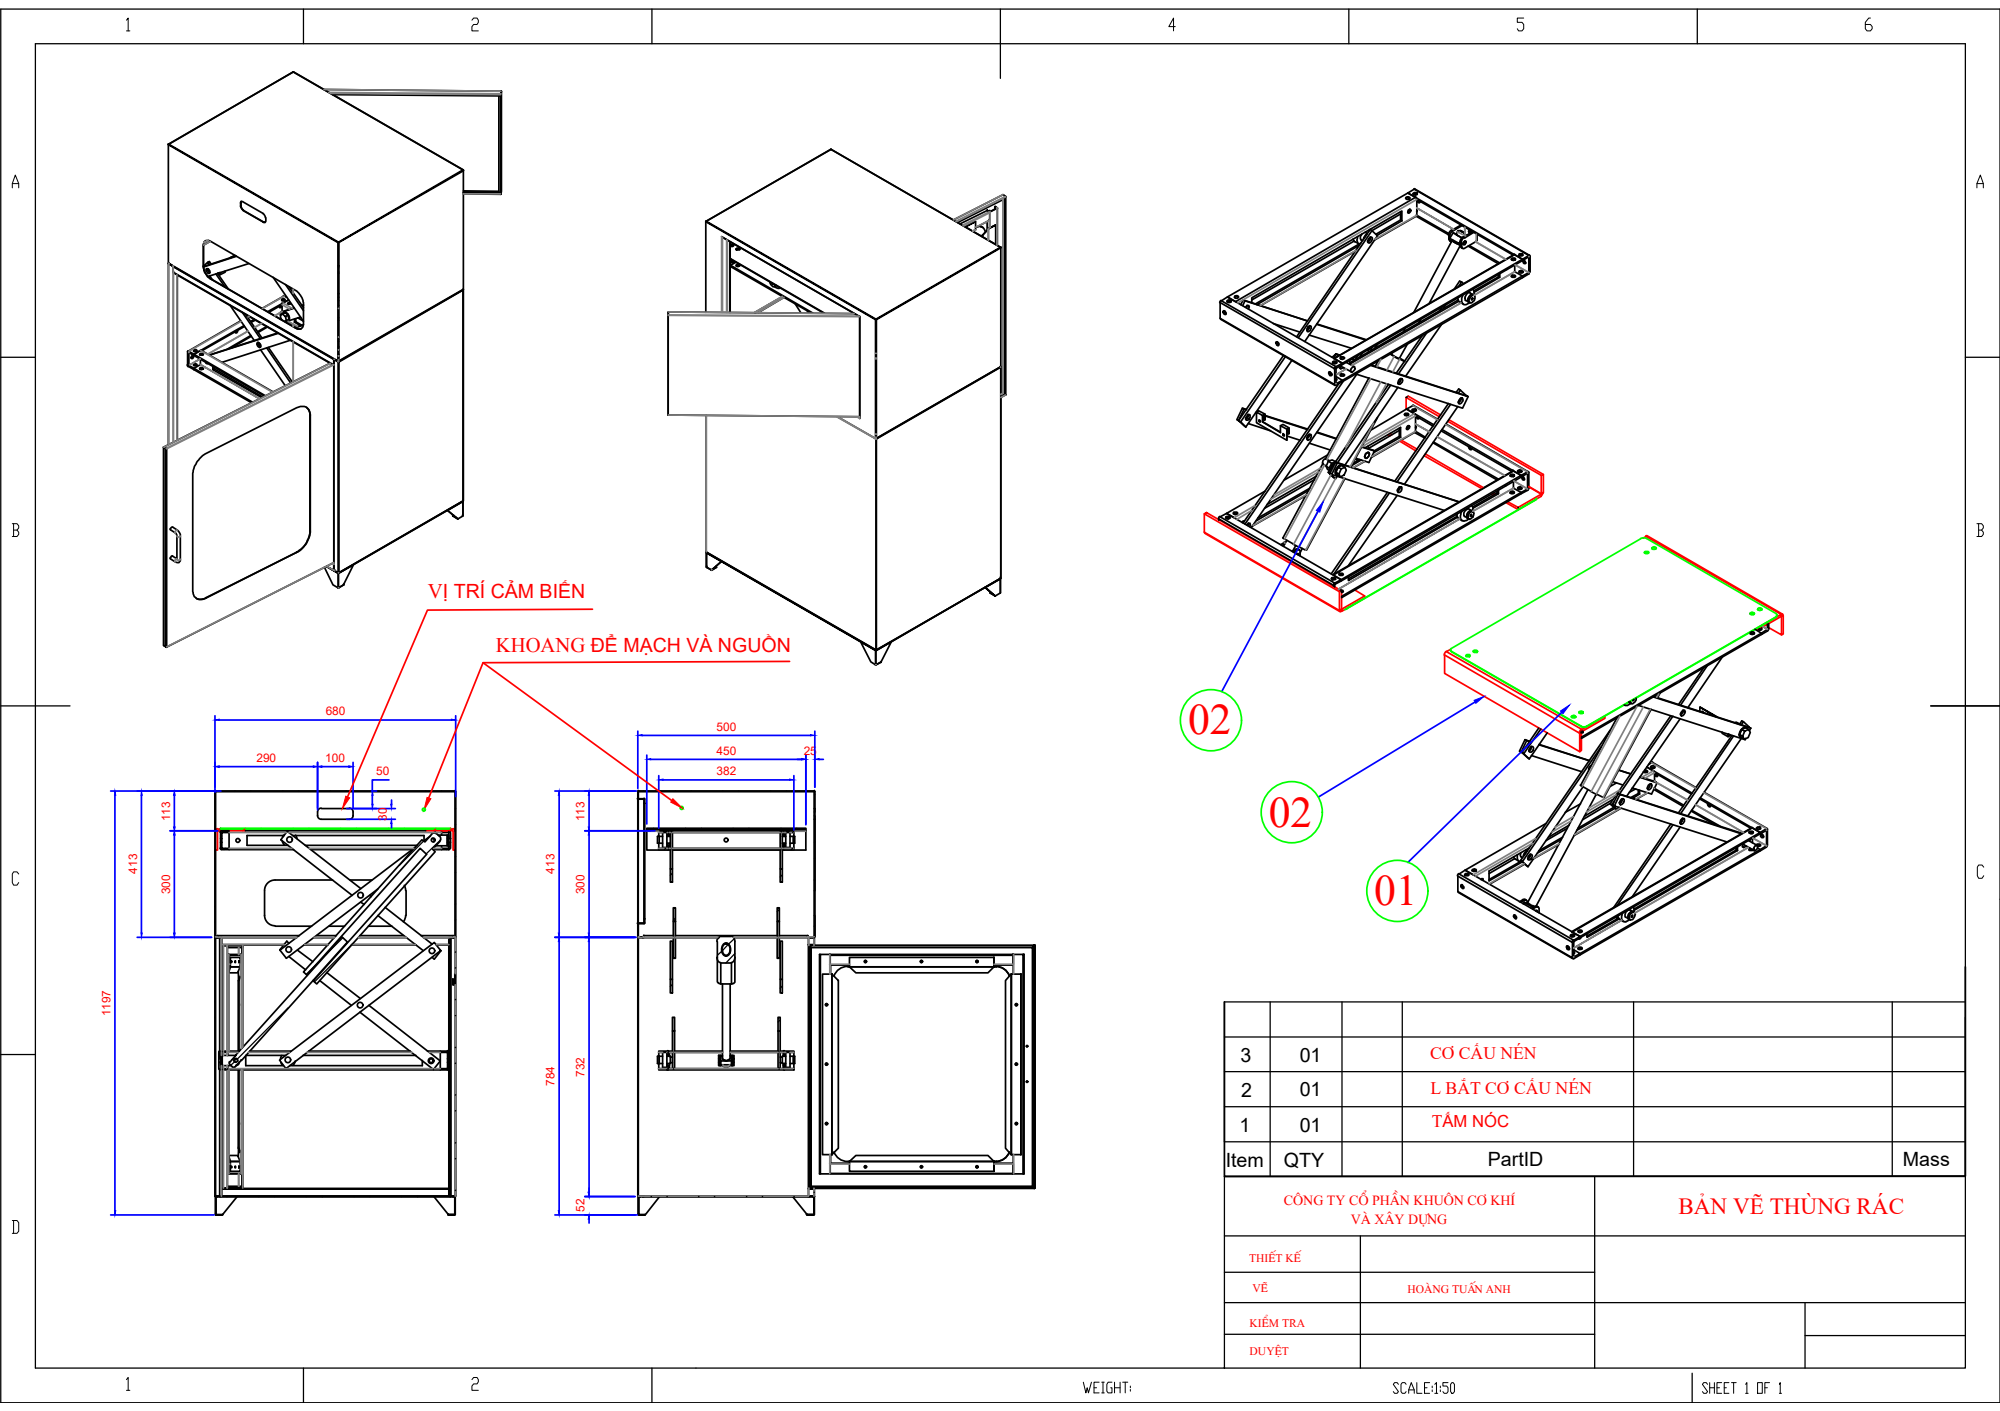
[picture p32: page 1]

VỊ TRÍ CẢM BIẾN

KHOANG ĐỂ MẠCH VÀ NGUỒN

3 | 01 | CƠ CẤU NÉN
2 | 01 | L BẮT CƠ CẤU NÉN
1 | 01 | TẤM NÓC

Item | QTY | PartID | Mass

BẢN VẼ THÙNG RÁC c«ng ty cæ phÇn khu«n c¬ khÝ vµ x©y dùng

thiÕt kÕ

vÏ | HOµNG TUÊN ANH

kiÓm tra

duyÖt

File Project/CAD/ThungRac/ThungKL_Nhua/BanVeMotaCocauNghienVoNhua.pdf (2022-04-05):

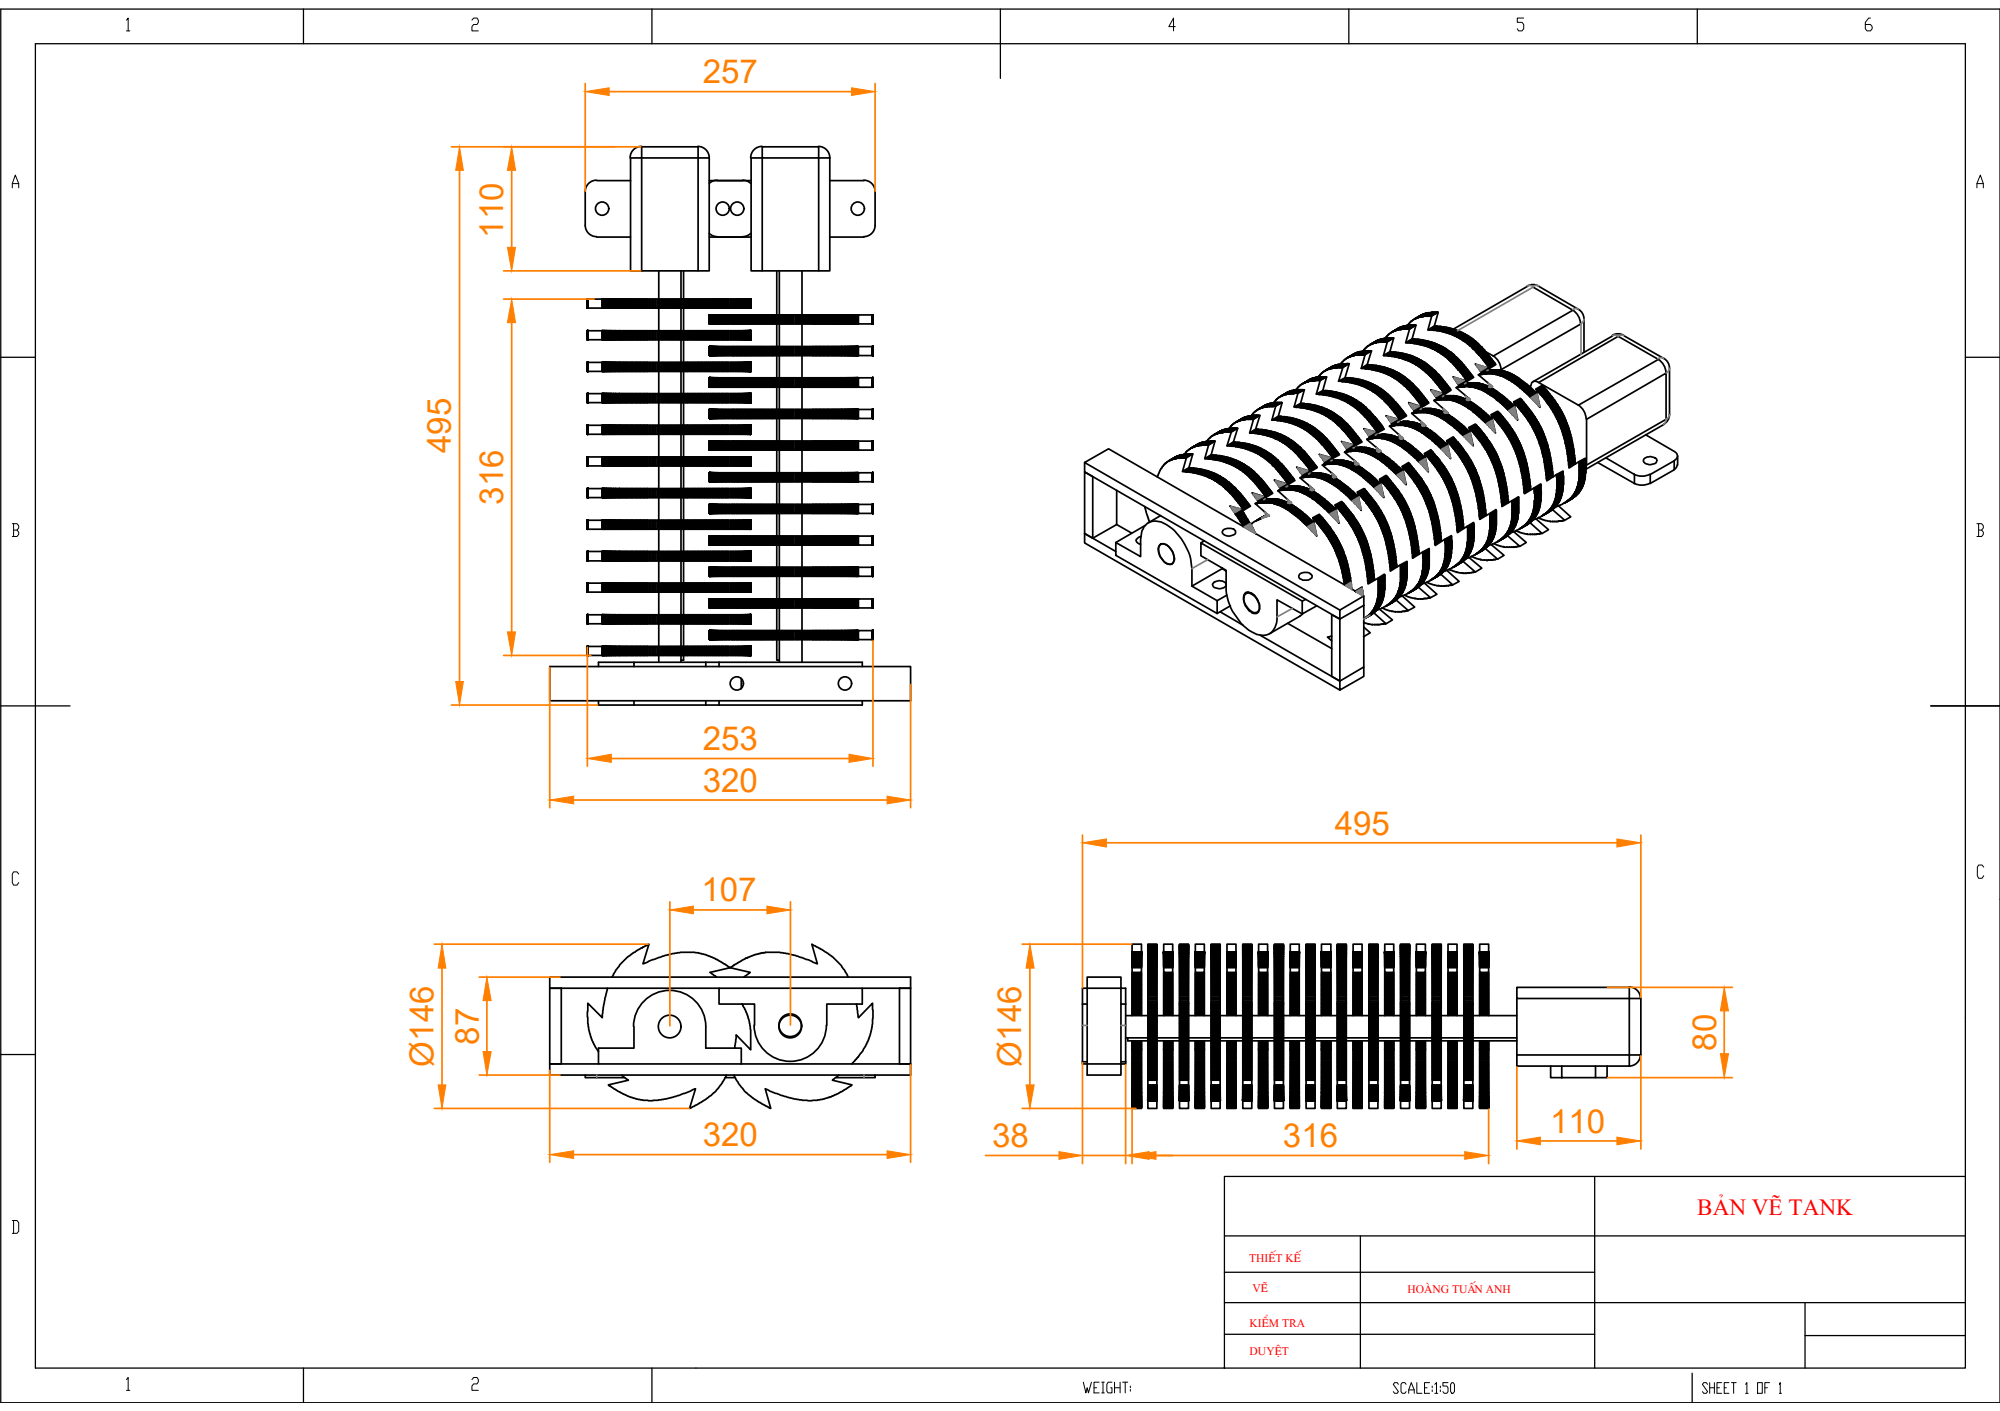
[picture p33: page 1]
thiÕt kÕ; kiÓm tra

BẢN VẼ TANK

HOµNG TUÊN ANH

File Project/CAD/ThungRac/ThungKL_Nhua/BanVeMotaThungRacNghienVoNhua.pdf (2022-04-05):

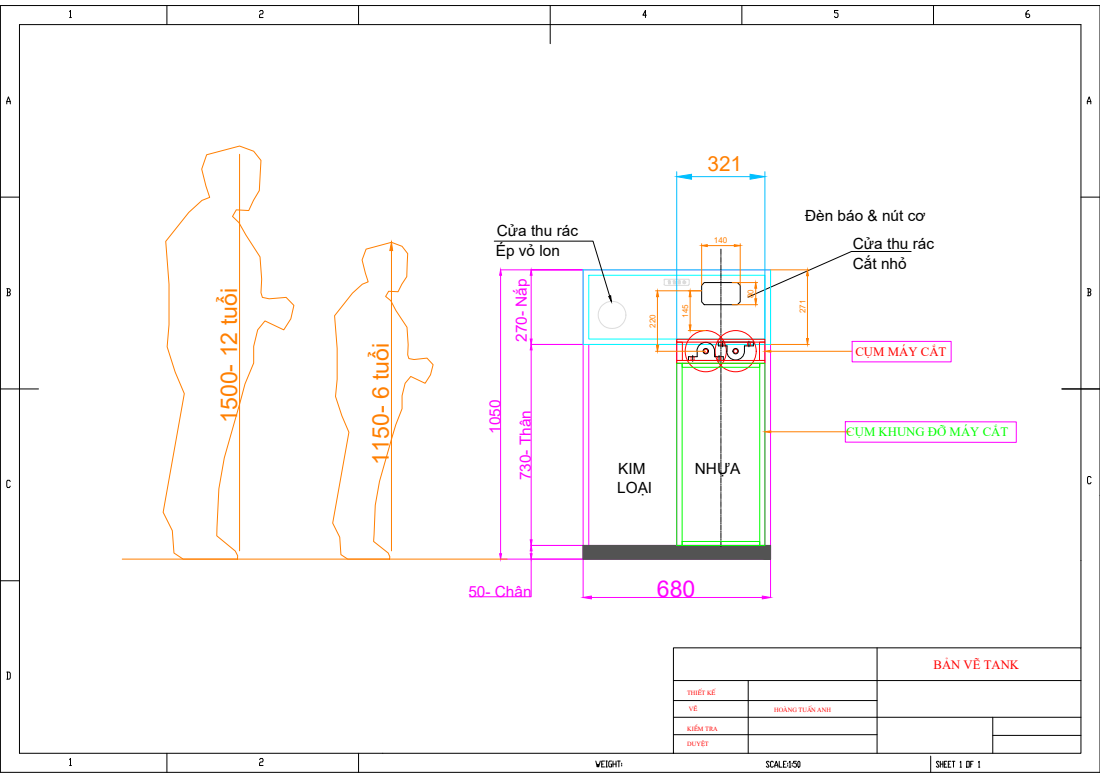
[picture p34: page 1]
730- Thân 270- Nắp; 50- Chân; 1500- 12 tuổi; 1150- 6 tuổi

Đèn báo & nút cơ

Cửa thu rác
Ép vỏ lon

Cắt nhỏ

CỤM MÁY CẮT

CỤM KHUNG ĐỠ MÁY CẮT

BẢN VẼ TANK

thiÕt kÕ

vÏ | HOµNG TUÊN ANH

kiÓm tra

duyÖt

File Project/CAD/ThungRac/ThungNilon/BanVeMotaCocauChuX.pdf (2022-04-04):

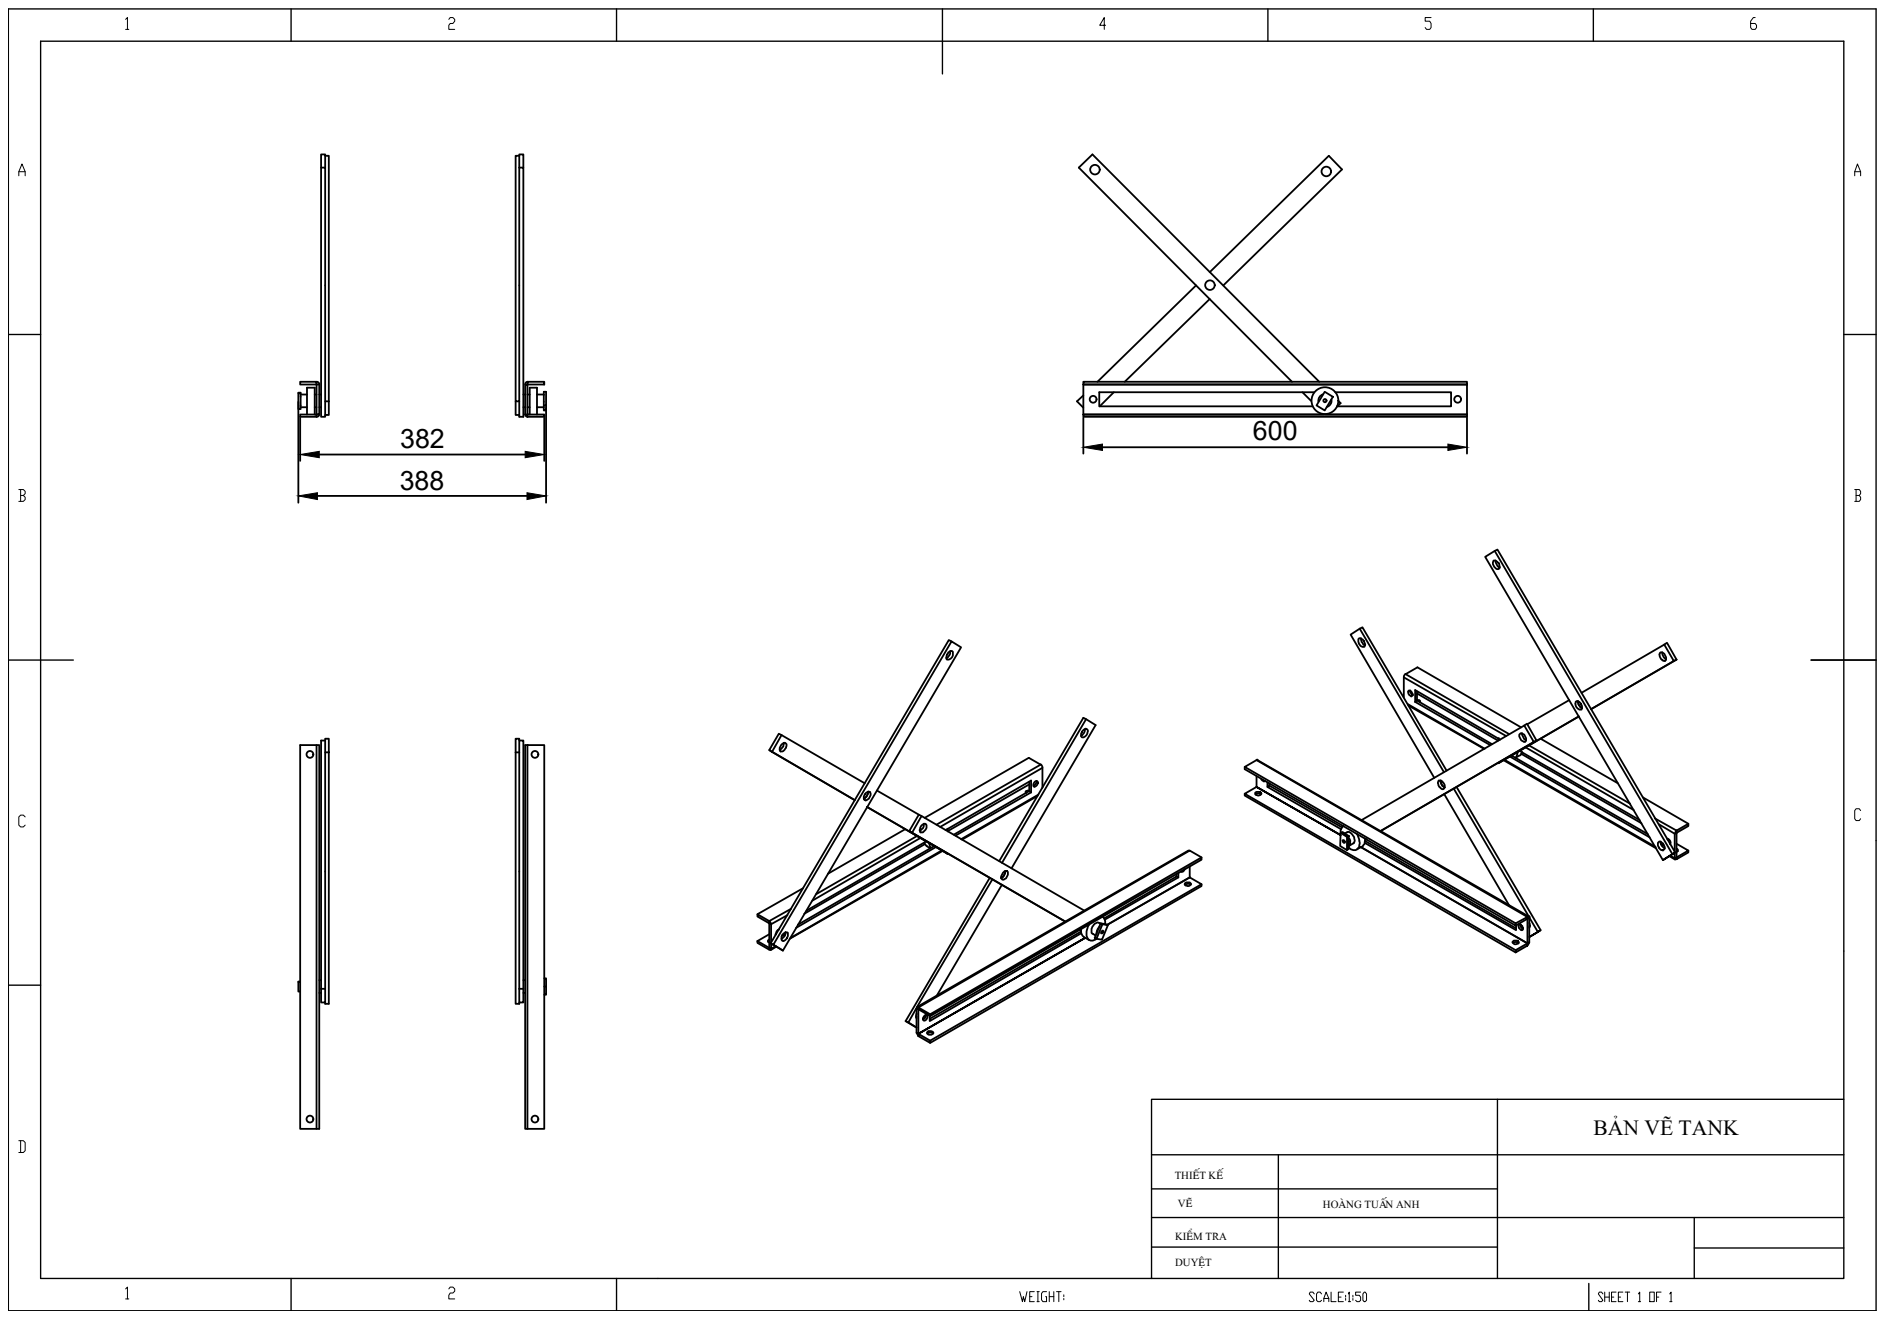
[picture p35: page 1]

BẢN VẼ TANK

thiÕt kÕ vÏ

HOµNG TUÊN ANH

kiÓm tra

duyÖt

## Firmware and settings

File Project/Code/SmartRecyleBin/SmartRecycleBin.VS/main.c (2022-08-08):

#include "main.h"
#include "Peripheral_Libs/Hearder/Configuration.h"
#include "Peripheral_Libs/Hearder/LoopProcess.h"
#include "Peripheral_Libs/Hearder/Interrupts.h"
#include "Peripheral_Libs/Hearder/GPIO.h"
#include "Peripheral_Libs/Hearder/HBrightCtrl.h"

void main(void)
{
    uint8_t test = 0;

    MCU_Config();
    GPIO_Write(Motor_0.Port, Motor_0.Pin, HIGH);

    if (GPIO_Read(SW1.Port, SW1.Pin) == HIGH)
    {
        test = 2;
    }
    else if (GPIO_Read(SW2.Port, SW2.Pin) == HIGH)
    {
        test = 3;
    }
    while (1)
    {
        if (test == 0)
        /*==================================*/
        {
            Loop(&timeSysTick);
        }
        /*==================================*/
        else if (test != 3)
        {
            /*============== Test ==============*/
            if (GPIO_Read(SW1.Port, SW1.Pin) == HIGH)
            {
                doorStepHandle.chieu = HIGH;
                doorStepHandle.vong = 400;
                Step_Set(&doorStepHandle);
                Step_Start(&doorStepHandle, &timeSysTick);
            }
            //Đi lên
            else if (GPIO_Read(SW2.Port, SW2.Pin) == HIGH)
            {
                doorStepHandle.chieu = LOW;
                doorStepHandle.vong = 400;
                Step_Set(&doorStepHandle);
                Step_Start(&doorStepHandle, &timeSysTick);
            }
            else
            {
                Step_Stop(&doorStepHandle);
            }
        }
        else
        {
            if (GPIO_Read(SW1.Port, SW1.Pin) == HIGH)
            {
                Motor_Forward_Start(&Compress_Motor);
            }
            //Đi xuống
            else if (GPIO_Read(SW2.Port, SW2.Pin) == HIGH)
            {
                Motor_Reverse_Start(&Compress_Motor);
            }
            else
            {
                Motor_Stop(&Compress_Motor);
            }
        }
        if (timeReset_flag != 0)
        {
            timeReset_flag = 0;
        }
        /*==================================*/
    }
}

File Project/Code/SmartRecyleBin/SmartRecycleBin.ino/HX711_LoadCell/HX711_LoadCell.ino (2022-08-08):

#include <Q2HX711.h>
#define D12 12
#define D13 13
const byte hx711_data_pin = 3;
const byte hx711_clock_pin = 2;

Q2HX711 hx711(hx711_data_pin, hx711_clock_pin);


float calib_value = 0.0;
void setup() {
  pinMode(D12, OUTPUT);
  pinMode(D13, OUTPUT);
  //Serial.begin(9600);
  for(int i = 0; i < 10; i++)
  {
    calib_value += (hx711.read()/100.0);
  }
  calib_value = calib_value/10;
}

void loop() {
  float limit_val = 0;
  for(int i = 0; i < 100; i++)
  {
    limit_val += analogRead(A0);
  }
  limit_val = limit_val/100;
  limit_val = limit_val * 20/1023;
  //Serial.print(limit_val);
  //Serial.println(" Val (Kg)");
  float val = hx711.read()/100.0 - calib_value;
  if(val < 0)
  {
    val = 0;
  }
  val = val/1000;
  //Serial.print(val);
  //Serial.println("Kg");

  if(val > limit_val)
  {
    digitalWrite(D13, HIGH);
    digitalWrite(D12, HIGH);
  }
  else
  {
    digitalWrite(D13, LOW);
    digitalWrite(D12, LOW);
  }
  
  delay(200);
}

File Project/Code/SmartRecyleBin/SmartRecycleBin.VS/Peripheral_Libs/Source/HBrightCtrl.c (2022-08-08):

/* 
 * File:   HBrightCtrl.h
 * Author: tuang
 *
 * Created on April 18, 2022, 12:04 AM
 */
#include "..\Hearder\GPIO.h"
#include "..\Hearder\HBrightCtrl.h"

void Delay_us(uint16_t time)
{
    while(time > 0)
    {
        time--;
        delay_us(1);
    }
}   

// void Delay_ms(uint16_t time)
// {
//     while(time > 0)
//     {
//         time--;
//         delay_ms(1);
//     }
// } 
uint8_t Motor_Read(Peripheral_Pin *motor_handle)
{
    if(GPIO_Read(motor_handle[forward_D3].Port, motor_handle[forward_D3].Pin) || GPIO_Read(motor_handle[forward_D1].Port, motor_handle[forward_D1].Pin))
    {
        return 1; //forward
    }
    if(GPIO_Read(motor_handle[reverse_D4].Port, motor_handle[reverse_D4].Pin) || GPIO_Read(motor_handle[reverse_D2].Port, motor_handle[reverse_D2].Pin))
    {
        return 2; //reverse
    }
    return 0;
}

void Motor_Stop(Peripheral_Pin *motor_handle)
{
    if(GPIO_Read(motor_handle[forward_D3].Port, motor_handle[forward_D3].Pin) || GPIO_Read(motor_handle[forward_D1].Port, motor_handle[forward_D1].Pin))
    {
        GPIO_Write(motor_handle[forward_D3].Port, motor_handle[forward_D3].Pin, LOW);
        GPIO_Write(motor_handle[reverse_D4].Port, motor_handle[reverse_D4].Pin, LOW);
        delay_us(10);
        GPIO_Write(motor_handle[forward_D1].Port, motor_handle[forward_D1].Pin, HIGH);
        GPIO_Write(motor_handle[reverse_D2].Port, motor_handle[reverse_D2].Pin, HIGH);
        delay_us(5);
        GPIO_Write(motor_handle[forward_D1].Port, motor_handle[forward_D1].Pin, LOW);
        delay_us(1);
        GPIO_Write(motor_handle[reverse_D4].Port, motor_handle[reverse_D4].Pin, HIGH);
        delay_us(100);
        GPIO_Write(motor_handle[reverse_D2].Port, motor_handle[reverse_D2].Pin, LOW);
        delay_us(1);
        GPIO_Write(motor_handle[forward_D3].Port, motor_handle[forward_D3].Pin, HIGH);
        delay_us(5);
        GPIO_Write(motor_handle[forward_D3].Port, motor_handle[forward_D3].Pin, LOW);
        GPIO_Write(motor_handle[reverse_D4].Port, motor_handle[reverse_D4].Pin, LOW);
        delay_ms(150);
    }
    else if(GPIO_Read(motor_handle[reverse_D4].Port, motor_handle[reverse_D4].Pin) || GPIO_Read(motor_handle[reverse_D2].Port, motor_handle[reverse_D2].Pin))/*reverse_D4 && reverse_D2*/
    {
        GPIO_Write(motor_handle[forward_D3].Port, motor_handle[forward_D3].Pin, LOW);
        GPIO_Write(motor_handle[reverse_D4].Port, motor_handle[reverse_D4].Pin, LOW);
        delay_us(10);
        GPIO_Write(motor_handle[forward_D1].Port, motor_handle[forward_D1].Pin, HIGH);
        GPIO_Write(motor_handle[reverse_D2].Port, motor_handle[reverse_D2].Pin, HIGH);
        delay_us(5);
        GPIO_Write(motor_handle[reverse_D2].Port, motor_handle[reverse_D2].Pin, LOW);
        delay_us(1);
        GPIO_Write(motor_handle[forward_D3].Port, motor_handle[forward_D3].Pin, HIGH);
        delay_us(5);
        GPIO_Write(motor_handle[forward_D1].Port, motor_handle[forward_D1].Pin, LOW);
        delay_us(1);
        GPIO_Write(motor_handle[reverse_D4].Port, motor_handle[reverse_D4].Pin, HIGH);
        delay_us(5);
        GPIO_Write(motor_handle[forward_D3].Port, motor_handle[forward_D3].Pin, LOW);
        GPIO_Write(motor_handle[reverse_D4].Port, motor_handle[reverse_D4].Pin, LOW);
        delay_ms(150);
    }
    
}
void Motor_Forward_Start(Peripheral_Pin *motor_handle)
{
    
    if(GPIO_Read(motor_handle[forward_D1].Port, motor_handle[forward_D1].Pin) == HIGH && GPIO_Read(motor_handle[forward_D3].Port, motor_handle[forward_D3].Pin) == HIGH)
    {

    }
    else
    {
        /*Stop the MOTOR*/
        Motor_Stop(motor_handle);
        /*Start the MOTOR to forward direction*/
        GPIO_Write(motor_handle[forward_D1].Port, motor_handle[forward_D1].Pin, HIGH);
        GPIO_Write(motor_handle[forward_D3].Port, motor_handle[forward_D3].Pin, HIGH);
    }
}
void Motor_Reverse_Start(Peripheral_Pin *motor_handle)
{
    if(GPIO_Read(motor_handle[reverse_D2].Port, motor_handle[reverse_D2].Pin) == HIGH && GPIO_Read(motor_handle[reverse_D4].Port, motor_handle[reverse_D4].Pin) == HIGH)
    {

    }
    else
    {
        /*Stop the MOTOR*/
        Motor_Stop(motor_handle);
        /*Start the MOTOR to reverse direction*/
        GPIO_Write(motor_handle[reverse_D2].Port, motor_handle[reverse_D2].Pin, HIGH);
        GPIO_Write(motor_handle[reverse_D4].Port, motor_handle[reverse_D4].Pin, HIGH);
    }
}


void Step_Set(StepHandle *stepHandle)
{
    GPIO_Write(stepHandle -> DIR_Pin.Port, stepHandle -> DIR_Pin.Pin, stepHandle -> chieu);
    stepHandle -> step = stepHandle -> vong * 1600;
}

void Step_Hold(StepHandle *stepHandle)
{
    stepHandle -> step = 0;
}

void Step_Stop(StepHandle *stepHandle)
{
    stepHandle -> step = 0;
    if(GPIO_Read(stepHandle -> ENA_Pin.Port, stepHandle -> ENA_Pin.Pin) == LOW)
    {
        GPIO_Write(stepHandle -> PUL_Pin.Port, stepHandle -> PUL_Pin.Pin, HIGH);
        GPIO_Write(stepHandle -> ENA_Pin.Port, stepHandle -> ENA_Pin.Pin, HIGH);
    }
}

void Step_Start(StepHandle *stepHandle, uint32_t *timeTick)
{
    if(stepHandle -> step > 0)
    {
        if(GPIO_Read(stepHandle -> ENA_Pin.Port, stepHandle -> ENA_Pin.Pin) == HIGH)
        {
            GPIO_Write(stepHandle -> ENA_Pin.Port, stepHandle -> ENA_Pin.Pin, LOW);
        }
        if(*timeTick % stepHandle -> speed == 0)
        {
            GPIO_Toggle(stepHandle -> PUL_Pin.Port, stepHandle -> PUL_Pin.Pin);
        }
        // GPIO_Write(stepHandle -> PUL_Pin.Port, stepHandle -> PUL_Pin.Pin, LOW);
        // Delay_us(stepHandle -> speed);
        // GPIO_Write(stepHandle -> PUL_Pin.Port, stepHandle -> PUL_Pin.Pin, HIGH);
        // Delay_us(stepHandle -> speed);
        stepHandle -> step -= 1;
    }
    // else
    // {
    //     GPIO_Write(stepHandle -> ENA_Pin.Port, stepHandle -> ENA_Pin.Pin, HIGH);
    // }
}

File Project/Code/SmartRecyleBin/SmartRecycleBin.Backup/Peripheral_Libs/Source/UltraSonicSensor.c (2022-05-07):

/* 
 * File:   UltraSonicSensor.c
 * Author: tuang
 *
 * Created on April 18, 2022, 4:43 PM
 */

#include "../Hearder/UltraSonicSensor.h"
#include "../Hearder/GPIO.h"


uint8_t UltraSonicSensor_Read(Peripheral_Pin *sensor, volatile uint16_t *system_tick)
{
    uint32_t buff_time = 0;
    GPIO_Write(sensor[TRIG].Port, sensor[TRIG].Pin, LOW);
    delay_us(2);
    GPIO_Write(sensor[TRIG].Port, sensor[TRIG].Pin, HIGH);
    delay_us(5);
    GPIO_Write(sensor[TRIG].Port, sensor[TRIG].Pin, LOW);
    if(!GPIO_Read(sensor[ECHO].Port, sensor[ECHO].Pin))
    {
        while(!GPIO_Read(sensor[ECHO].Port, sensor[ECHO].Pin));
    }
    buff_time = *system_tick;
    while(GPIO_Read(sensor[ECHO].Port, sensor[ECHO].Pin))
    {
        if(*system_tick - buff_time > 300)
        {
            break;
        }
    }
    buff_time = *system_tick - buff_time;
    
    if (buff_time > 150)
    {
        buff_time = 0;
    }
    return buff_time;
}

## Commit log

2022-03-29 update Altium
    [Smart_Reclyce_Bin.PcbDoc, Smart_Reclyce_Bin.PrjPcb, Smart_Reclyce_Bin.SchDoc]
2022-03-29 Update Old Documents
    [Dự toán thùng rác thông minh.xlsx, Infor_Timeline.xlsx, Infor_Timeline_SmartRecycleBin_20220319.xlsx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]
2022-03-29 hop dong- ban mau cho du an thung rac thong minh
    hợp đồng bản mẫu
2022-03-29 hop dong mau
    hợp đồng mẫu cho dự án thùng rác thông minh
2022-03-31 Update folder format
    [Smart_Reclyce_Bin.PcbDoc, Smart_Reclyce_Bin.PrjPcb, Smart_Reclyce_Bin.SchDoc]
2022-04-01 add altium
    [Hbridge.SchDoc, MCU.SchDoc, Sensor.SchDoc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]
2022-04-02 Update Customer datas
    [Button.SchDoc, Hbridge.SchDoc, Led&Speaker.SchDoc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]
2022-04-02 update test
    [phuong an SRB.dwg]
2022-04-02 update test folder
    [phuong an SRB.dwg]
2022-04-02 test delete folder
    [phuong an SRB.dwg]
2022-04-03 update altium new
    [Button.SchDoc, Hbridge.SchDoc, Led&Speaker.SchDoc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]
2022-04-03 remove altium
    [Button.SchDoc, Hbridge.PcbDoc, Hbridge.SchDoc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]
2022-04-04 altium new
    [Button.SchDoc, Hbridge.SchDoc, Led&Speaker.SchDoc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]
2022-04-06 Update cautructhumuc Project/CAD
2022-04-08 Up file lien he
    [Button.PcbDoc, Hbridge.PcbDoc, MCU.PcbDoc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]
2022-04-12 Update report - Tuan 3
    [SmartRecycleBin_Timeline_20220405_20220502.xlsx]
2022-04-16 Update SmartRecycleBin Main Code
    [Configuration.h]
2022-04-19 Update source code
    [Configuration.h]
2022-04-19 Update Report Tuan 4
    [SmartRecycleBin_Timeline_20220405_20220502.xlsx]
2022-04-20 Update VS code
    [Configuration.h]
2022-08-08 Update new source code
    [Configuration.h, Hbridge.PcbDoc, Kế hoạch công việc bằng excel.xlsx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]
